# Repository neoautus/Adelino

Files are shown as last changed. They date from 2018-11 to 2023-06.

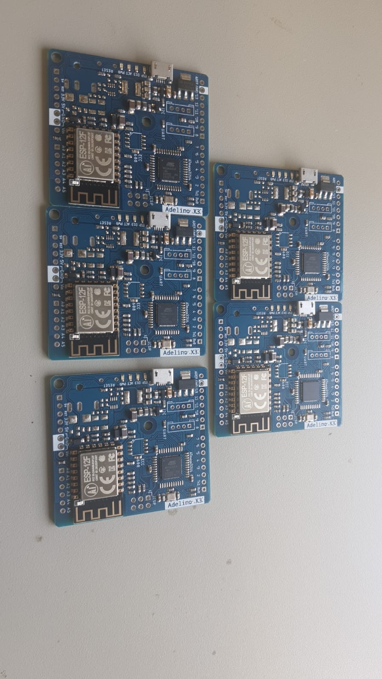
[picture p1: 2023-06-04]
Pics/Adelinos_testados.jpeg

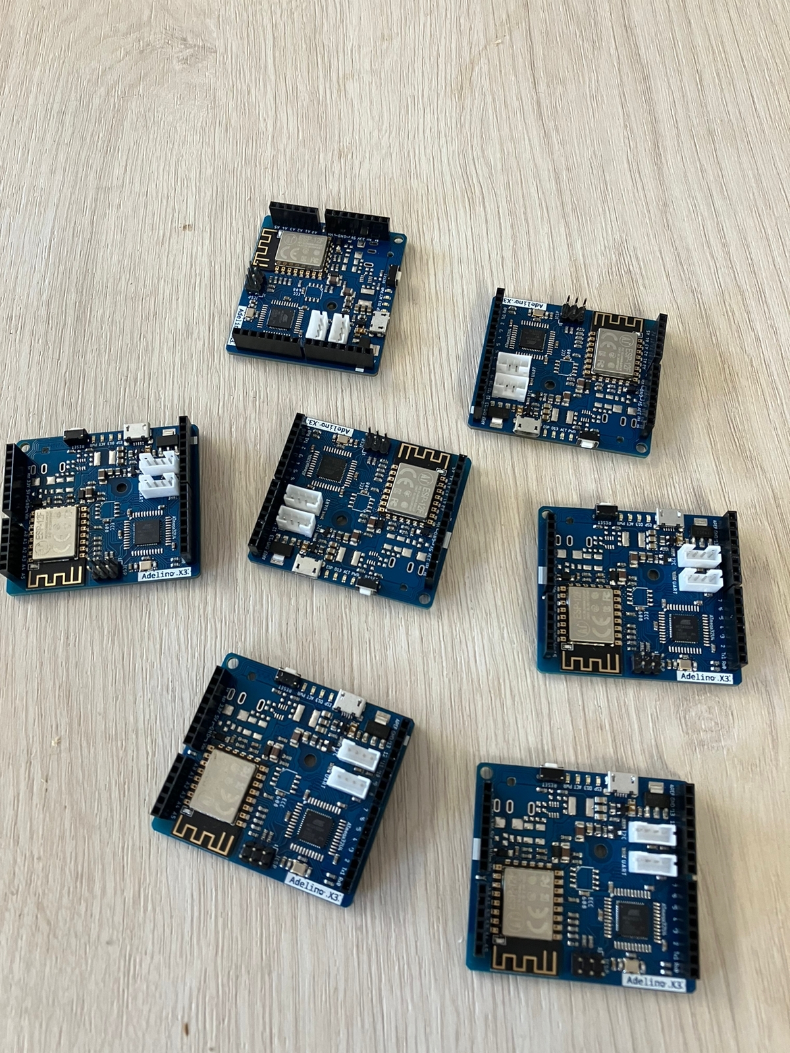
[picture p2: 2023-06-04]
Pics/Adelinos_festando.jpeg

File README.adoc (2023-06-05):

= Adelino
:page-layout: book

O Adelino é uma placa de desenvolvimento baseada no ATmega32U4 com um módulo ESP-12F integrado.
Ela foi inicialmente inspirada no Arduino Leonardo e no Arduino Yún.

Visite nosso https://github.com/neoautus/Adelino/wiki[Wiki] para conhecer melhor este produto!

'''

Adelino is an ATmega32U4 development board with integrated ESP-12F module.
It was initially inspired by Arduino Leonardo and Arduino Yún.

Visit our https://github.com/neoautus/Adelino/wiki[Wiki] for more information!

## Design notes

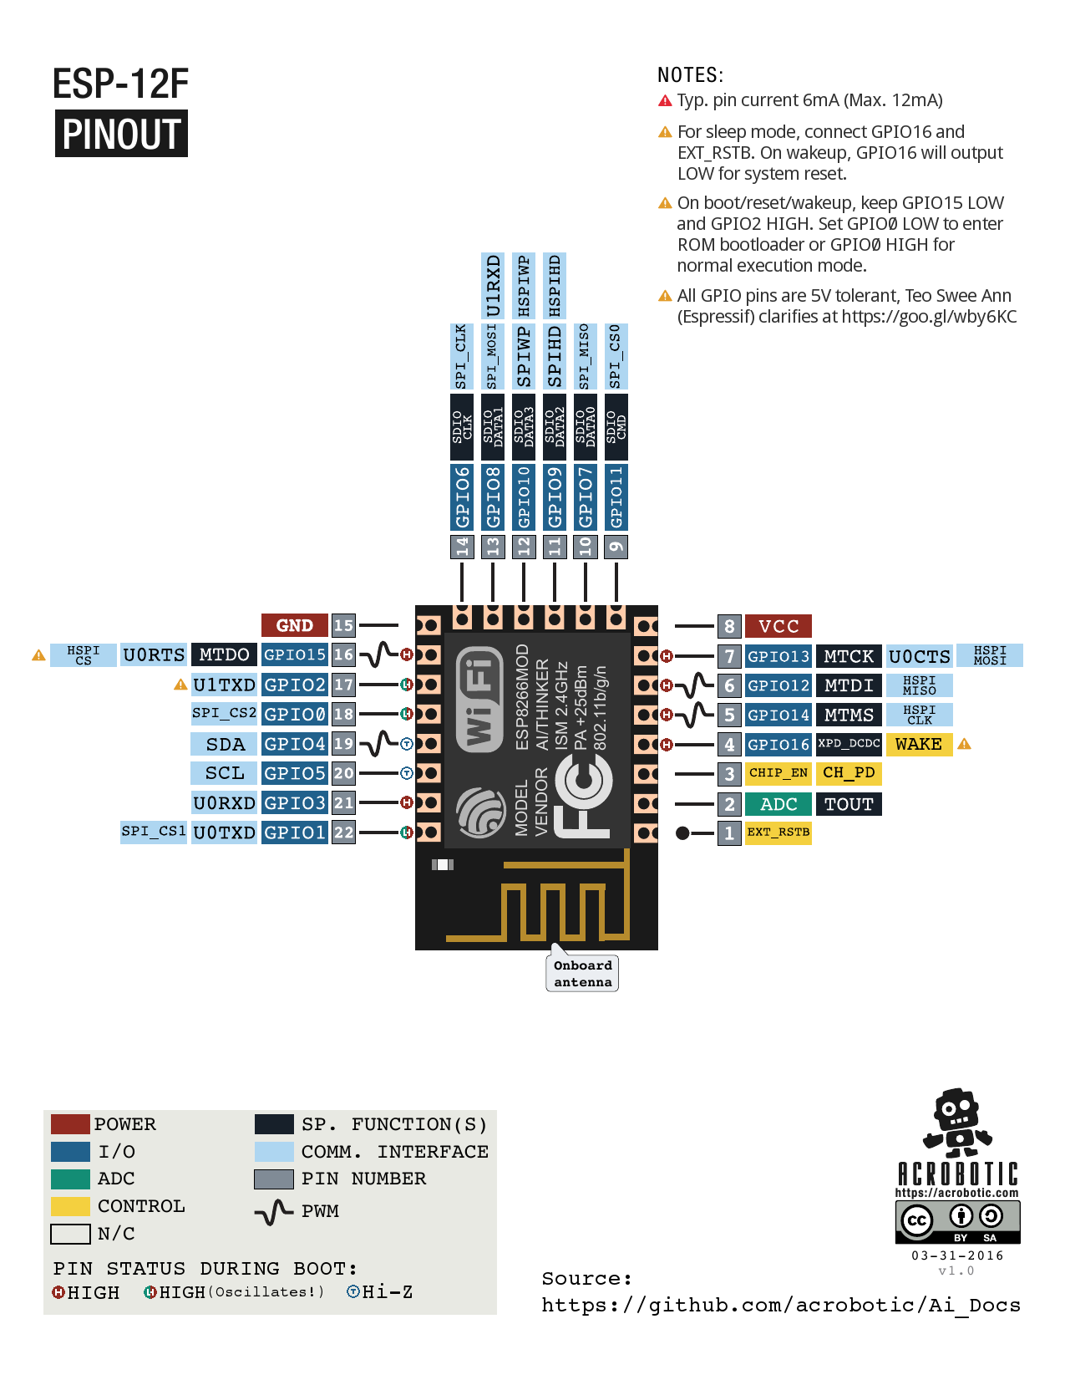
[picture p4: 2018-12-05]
Docs/ESP-12F_Pinout.png

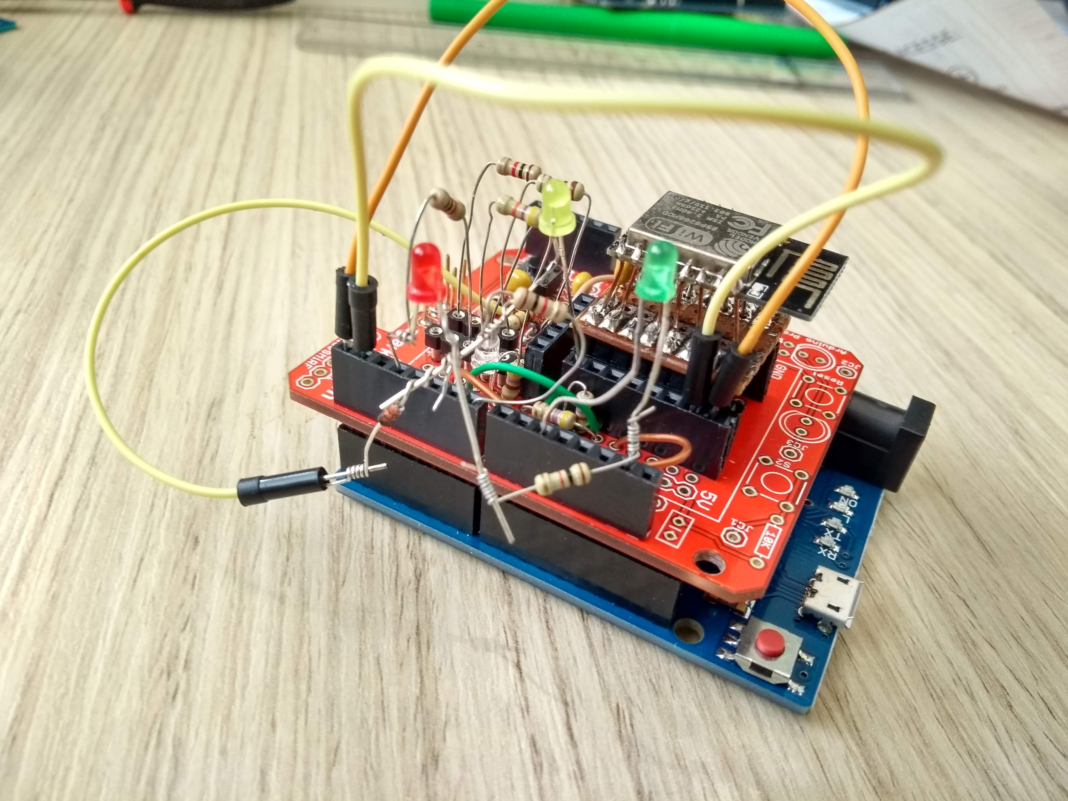
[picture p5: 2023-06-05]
Pics/Prototipagem_adelino.jpg

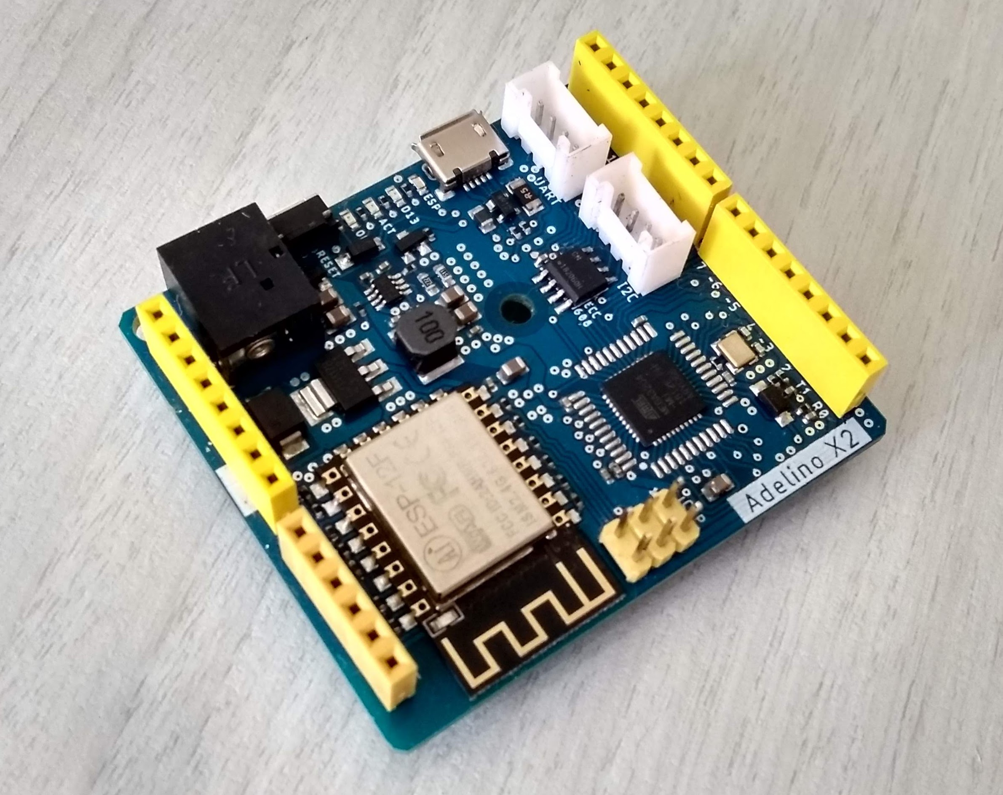
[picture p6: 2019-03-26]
Adelino_X2.jpg

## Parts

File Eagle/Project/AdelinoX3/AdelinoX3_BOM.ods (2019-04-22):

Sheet: AdelinoX3_BOM_Eagle
Parts | Qty | Value | Device | Package | Description | DESC | LABEL | MOUSER_REF | MPN | R | SKU | TP_SIGNAL_NAME | VALUE
C1, C2, C3, C4 | 4 | 22uf | CERAMIC-22UF-16V-10%-X7R(1206) | C1206 | 302010182
C14, C15 | 2 | 22pf | CERAMIC-22PF-50V-5%-NPO(0603) | C0603 | 302010143 |  |  |  | CC0603JRNPO9BN220 |  |  |  | 22pf
C22 | 1 | 1uf | CERAMIC-1UF-25V-10%-X7R(0603) | C0603 | 302010139 |  |  |  | CC0603KRX7R8BB105 |  |  |  | 1uf
C5, C7, C12, C13, C16, C17, C18, C19, C20, C21, C23 | 11 | 100nf | CERAMIC-100NF-50V-10%-X7R(0603) | C0603 | 302010138 |  |  |  | CC0603KRX7R9BB104 |  |  |  | 100nf
C6 | 1 | 22nf | CERAMIC-22NF-50V-10%-X7R(0603) | C0603 | 302010095 |  |  |  | CC0603KRX7R9BB223 |  |  |  | 22nf
C8, C9, C10, C11 | 4 | 10uf | CERAMIC-10UF-25V-10%-X5R(0805) | C0805 | 302010178 |  |  |  | CC0805KKX5R8BB106 |  |  |  | 10uf
D1 | 1 | TVS-DIODE-SZOPL-SMBJ15CA-13-F | TVS-DIODE-SZOPL-SMBJ15CA-13-F | DO-214AA | SMBJ15CA-13-F |  |  |  | SMBJ15CA-13-F |  | SHENZHEN-OPL | TVS DIODE 15VWM 24.4VC SMB
D2, D3 | 2 | 20V-500MA | SMD-DIODE-SCHOTTKY-20V-500MA(SOD-123)P | SOD-123 | 304020028 |  |  |  | MBR0520LT1G |  |  |  | 20V-500MA
D4 | 1 | BLUE-0603 | SMD-LED-CLEAR-BLUE(0603) | LED-0603 | 304090045 |  | ESP |  | 19-217-BHC-ZL1M2RY-3T |  |  |  | BLUE-0603
D5 | 1 | GREEN-0603 | SMD-LED-CLEAR-GREEN(0603) | LED-0603 | 304090043 |  | PWR |  | 19-217-G7C-AN1P2-3T |  |  |  | GREEN-0603
D6 | 1 | YELLOW-0603 | SMD-LED-CLEAR-YELLOW(0603) | LED-0603 | 304090044 |  | ACT |  | 19-217-Y5C-AM1N1VY-3T |  |  |  | YELLOW-0603
D7 | 1 | YEL-0603 | SMD-LED-CLEAR-YELLOW(0603) | LED-0603 | 304090044 |  | D13 |  | 19-217-Y5C-AM1N1VY-3T |  |  |  | YELLOW-0603
ESD1 | 1 | PRTR5V0U2X | SMD-DIODE-TVS-5.5V | SOT-143B | 304050022 |  |  |  | NXP | PRTR5V0U2X,215 |  | 304050022
F1 | 1 | SMD1206R500SF | SMD-PPTC-500MA(1206) | F1206 | 307010002 |  |  |  | SMD1206R500SF |  |  |  | SMD1206R500SF
J1 | 1 | DC-044-A | JACK-DC-044-A | DCJ3P-11.6X9.6X7.0MM | 320120002 |  |  |  | JACK-DC-044-A |  |  |  | DC-044-A
J2, J4, J5 | 3 | YELLOW-8P-2.54 | DIP-YELLOW-FEMALE-HEADER(8P-2.54) | H8-2.54 | 320030065 |  |  |  | F185-1108A1BSYC1 |  |  |  | YELLOW-8P-2.54
J3 | 1 | YELLOW-6P-2.54 | DIP-YELLOW-FEMALE-HEADER-VERT(6P-2.54) | H6-2.54 | 320030019 |  |  |  | F185-1106A1BSYA3 |  |  |  | YELLOW-6P-2.54
J6, J8 | 2 | 4P-2.0 | GROVE-CONNECTOR-DIP(4P-2.0) | HW4-2.0 | 320110033 |  |  |  |  |  |  |  | 4P-2.0
J7 | 1 | YELLOW-2X3P-2.54 | DIP-YELLOW-MALE-HEADER-VERT(2X3P-2.54) | H2X3-2.54 | 320020027 |  |  |  | P125-1203A0BS116A2 |  |  |  | YELLOW-2X3P-2.54
L1, L4 | 2 | 470R-2A | SMD-FERRITE-BEAD-470R-2A(0805)'0805' | L0805 | 303030008 |  |  |  | WLB2012-471T20 |  |  |  | 470R-2A
L2 | 1 | 330R-1500MA | SMD-FERRITE-BEAD-330R-1500MA(0805)'0805' | L0805 | 303030006 |  |  |  | BLM21PG331SN1D |  |  |  | 330R-1500MA
L3 | 1 | 10UH-225MA | SMD-INDUCTOR-10UH-20%-2.35A(2P-5X5X4MM) | L5040S | 303010147
Q1 | 1 | NCE3407A | SMD-MOSFET-P-CH-VDC=30V-ID=4.3A-NCE3407A(SOT-23) | SOT-23 | 305030010 |  |  |  | NCE3407A |  |  |  | NCE3407A
Q2 | 1 | CJ2305 | SMD-MOSFET-P-CH-8V-4.1A-CJ2305(SOT-23) | SOT-23 | 305030014 |  |  |  | CJ2305 |  |  |  | CJ2305
R1, R9, R10, R11, R21 | 5 | 100K | SMD-RES-100K-5%-1/10W(0603) | R0603 | 301010089 |  |  |  | RC0603JR-07100KL |  |  |  | 100K 1/10W
R12, R14, R15, R24, R29 | 5 | 10K | SMD-RES-10K-5%-1/10W(0603) | R0603 | 301010293 |  |  |  | RC0603JR-0710KL |  |  |  | 10K 1/10W
R13 | 1 | 1M | SMD-RES-1M-5%-1/10W(0603) | R0603 | 301010100 |  |  |  | RC0603JR-071ML |  |  |  | 1M 1/10W
R16, R17, R18, R19, R22, R23, R25, R26, R27, R28 | 10 | 1K | SMD-RES-1K-5%-1/10W(0603) | R0603 | 301010291 |  |  |  | RC0603JR-071KL |  |  |  | 1K 1/10W
R2 | 1 | 24K | SMD-RES-24K-1%-1/10W(0603) | R0603 | 301010232
R20 | 1 | 0R | SMD-RES-0R-5%-1/10W(0603) | R0603 | 301010292 |  |  |  | RC0603JR-070RL |  |  |  | 0R
R3, R4 | 2 | 22R | SMD-RES-22R-5%-1/10W(0603) | R0603 | 301010289 |  |  |  | RC0603JR-0722RL |  |  |  | 22R
R30 | 1 | 470R | SMD-RES-470R-5%-1/10W(0603) | R0603 | 301010088 |  |  |  | RC0603JR-07470RL |  |  |  | 470R
R5 | 1 | 10R | SMD-RES-10R-1%-1/10W(0603) | R0603 | 301010185 |  |  |  | RC0603FR-0710RL |  |  |  | 10R
R6 | 1 | 3.3K | SMD-RES-3.3K-5%-1/10W(0603) | R0603 | 301010112
R7 | 1 | 3K / 1% | SMD-RES-510R-1%-1/10W(0603) | R0603 | 301010215 |  |  |  |  | 510R / 1%
R8 | 1 | 2K7 / 1% | SMD-RES-2.7K-1%-1/10W(0603) | R0603 | 301010193 |  |  |  |  | 2K7 / 1%
SW1 | 1 | TS-1101F | DIP-BUTTON(2P-6.0X3.0X4.3MM)-TS-1101F | SW2-5.0-6.0X3.0X4.3MM | 311020025 |  |  |  | TS-1101F |  |  |  | TS-1101F
U1 | 1 | CJT1117-3.3 | PMIC-CJT1117-3.3(SOT223) | SOT-223 | 310030097 |  |  |  | CJT1117-3.3 |  |  |  | CJT1117-3.3-SOT223
U2 | 1 | MP1496DJ-SOT23-8 | PMIC-MP1496DJ(SOT23-8) | SOT-23-8 | 310030121 |  |  |  | MP1496DJ |  |  |  | MP1496DJ-SOT23-8
U3 | 1 | ESP-12F / OPL: 317060163 | ESP-12F | ESP-12F | 317060163
U4 | 1 | DNP | ATECC608(SOIC8) | SOIC8-1.27-5X4MM | ATECC608A-SSHDA-B (SOIC-8) | ATECC608A-SSHDA-B (SOIC-8) |  | https://www.mouser.com/ProductDetail/556-ATECC608ASSHDAB | ATECC608A-SSHDA-B |  |  |  | ATECC608-SOIC8
U5 | 1 | ATMEGA32U4-MUR-QFN44 | MCU-ATMEGA32U4-MUR(VQFN44) | QFN44G-0.5-7X7MM | 310010016 | Primary socket - QFN44 |  |  | ATMEGA32U4-MUR |  |  |  | ATMEGA32U4-MUR-QFN44
USB1 | 1 | ST-USB-001G | MICRO-USB-SMD-B-WITHOUT-POST-W/P(ST-USB-001G) | MICRO-USB5+4P-SMD-0.65-B | 320010000 |  |  |  | ST-USB-001G |  |  |  | ST-USB-001G
X1 | 1 | 306010049_XTAL_16MHZ-3225_4P | 306010049_XTAL_16MHZ-3225_4P | X3225_4P | 306010049

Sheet: AdelinoX3_BOM_Seeed
Designator | MPN / Seeed SKU | Qty | Link
C1, C2, C3, C4 | 302010182 | 4
C14, C15 | 302010143 | 2
C22 | 302010139 | 1
C5, C7, C12, C13, C16, C17, C18, C19, C20, C21, C23 | 302010138 | 11
C6 | 302010095 | 1
C8, C9, C10, C11 | 302010178 | 4
D1 | SMBJ15CA-13-F | 1 | ShenZhen OPL
D2, D3 | 304020028 | 2
D4 | 304090045 | 1
D5 | 304090043 | 1
D6 | 304090044 | 1
D7 | 304090044 | 1
ESD1 | 304050022 | 1
F1 | 307010002 | 1
J1 | 320120002 | 1
J2, J4, J5 | 320030065 | 3
J3 | 320030019 | 1
J6, J8 | 320110033 | 2
J7 | 320020027 | 1
L1, L4 | 303030008 | 2
L2 | 303030006 | 1
L3 | 303010147 | 1
Q1 | 305030010 | 1
Q2 | 305030014 | 1
R1, R9, R10, R11, R21 | 301010089 | 5
R12, R14, R15, R24, R29 | 301010293 | 5
R13 | 301010100 | 1
R16, R17, R18, R19, R22, R23, R25, R26, R27, R28 | 301010291 | 10
R2 | 301010232 | 1
R20 | 301010292 | 1
R3, R4 | 301010289 | 2
R30 | 301010088 | 1
R5 | 301010185 | 1
R6 | 301010112 | 1
R7 | 301010215 | 1
R8 | 301010193 | 1
SW1 | 311020025 | 1
U1 | 310030097 | 1
U2 | 310030121 | 1
U3 | 317060163 | 1
U4 | ATECC608A-SSHDA-B (SOIC-8) | 1 | https://www.mouser.com/ProductDetail/556-ATECC608ASSHDAB
U5 | 310010016 | 1
USB1 | 320010000 | 1
X1 | 306010049 | 1

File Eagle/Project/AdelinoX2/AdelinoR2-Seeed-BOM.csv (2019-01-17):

Designator | MPN / Seeed SKU | Qty | Link
C1, C4, C5, C8, C11, C14, C15, C16, C17, C18, C19, C21 | 302010024 | 12
C12, C13 | 302010018 | 2
C2, C3, C6, C9, C10 | 302010178 | 5
C20 | 302010179 | 1
C7 | 302010242 | 1
D1 | SMBJ15CA-13-F | 1 | ShenZhen OPL
D2, D5 | 304020028 | 2
D3 | 304090043 | 1
D4 | 304090044 | 1
D6 | 304090044 | 1
D7 | 304090045 | 1
ESD1 | 304050022 | 1
F1 | 307010002 | 1
J1 | 320120002 | 1
J2, J4, J5 | 320030065 | 3
J3 | 320030019 | 1
J6, J8 | 320110033 | 2
J7 | 320020027 | 1
L1 | 303030006 | 1
L2 | 303010147 | 1
Q1 | 305030010 | 1
Q2 | 305030014 | 1
R1, R8, R9, R10 | 301010456 | 4
R11, R13, R14, R20, R23, R29 | 301010047 | 6
R12 | 301010043 | 1
R15, R16, R17, R18, R21, R22, R24, R25, R26, R27 | 301010006 | 10
R19 | 301010000 | 1
R2, R3 | 301010052 | 2
R28 | 301010013 | 1
R4 | 301010444 | 1
R5 | 301010035 | 1
R6 | 301010215 | 1
R7 | 301010193 | 1
SW1 | 311020025 | 1
U1 | 310030097 | 1
U2 | 310030121 | 1
U3 | 317060163 | 1
U5 | 310010016 | 1
USB1 | 320010000 | 1
X1 | 306010049 | 1

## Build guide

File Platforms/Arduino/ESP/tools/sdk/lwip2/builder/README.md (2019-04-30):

# lwIP-2 from original source

This repo offers a link layer for esp82xx-nonos-sdk-2.
The original goal is to try and use a recent lwIP version for stability reasons.
Currently lwIP-v2 is implemented, other IP stacks could be tried.

current lwIP link: [STABLE_2.1.2](http://git.savannah.nongnu.org/cgit/lwip.git/tree/?h=STABLE-2_1_2_RELEASE)

# Status

* UDP/TCP codes using lwIP-1.4 need some updates - two examples: [arduino](https://github.com/esp8266/Arduino/pull/3129) and [sming](https://github.com/SmingHub/Sming/pull/1147)
* IPv6 working in Arduino
* SACK-out enabled in Arduino
* tcp is more stable ([example1](https://github.com/esp8266/Arduino/issues/3075) and [example2](https://github.com/esp8266/Arduino/issues/2925))
* used by default in esp8266 arduino core
* accepted pull request in [esp8266/arduino](https://github.com/esp8266/Arduino/pull/3783)
* (WIP) [sming](https://github.com/SmingHub/Sming/pull/1147)
* (WIP) [esp-open-sdk](https://github.com/pfalcon/esp-open-sdk/pull/271)

# Build

[with Arduino](https://github.com/esp8266/Arduino/tree/master/tools/sdk/lwip2)

# MSS

Remember the MSS footprint: 4\*MSS bytes in RAM per tcp connection.
The lowest recommanded value is 536.

# How it works

Espressif binary libraries rely on their lwip implementation. The idea, as
described in this [comment](https://github.com/kadamski/esp-lwip/issues/8)
is to wrap espressif calls, and rewrite them for a new tcp implementation.

Example with lwip1.4's ethernet_input() called by espressif binary blobs
finally reaching lwip2's:

```
-- LWIP2-----------------------------------
#define ethernet_input ethernet_input_LWIP2
- lwip2's ethernet_input_LWIP2_is called
                            (/ \)
                             | |
-- glue (new side)-----------^-v-----------
                             | |
glue_ethernet_input          | |
- maps structures glue->new  |
- calls ethernet_input_LWIP2(^ v)
- maps structures new->glue    |
                             | |
-- glue (old side)-----------^-v-----------
                             | |
ethernet_input():            | |
- maps structures old->glue  | 
- calls glue_ethernet_input (^ v)
- maps structures glue->old    |
                             | |
- espressif blobs -----------^-v-----------
XXXXXXXXXXXXXXXXXXXXXXXXXXXX | | XXXXXXXXXX
wifi calls    ethernet_input(/ \) XXXXXXXXX
XXXXXXXXXXXXXXXXXXXXXXXXXXXXXXXXXXXXXXXXXXX
-------------------------------------------
```

# History

Original [cleaning and port](https://github.com/nekromant/esp8266-frankenstein/tree/master/src/contrib/lwipupdate) of espressif's patch set from lwIP-v1.4 to lwIP-v2 with references to lwIP-git-sha1

[Discussion](https://github.com/kadamski/esp-lwip/issues/8) on how further work could done

[First](https://github.com/d-a-v/esp8266-phy) version of this implementation

[Second](https://github.com/esp8266/Arduino/pull/3206) version for arduino only

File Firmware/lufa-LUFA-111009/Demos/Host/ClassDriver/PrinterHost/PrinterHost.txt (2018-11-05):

/** \file
 *
 *  This file contains special DoxyGen information for the generation of the main page and other special
 *  documentation pages. It is not a project source file.
 */

/** \mainpage Printer Host Demo
 *
 *  \section Sec_Compat Demo Compatibility:
 *
 *  The following list indicates what microcontrollers are compatible with this demo.
 *
 *  - Series 7 USB AVRs (AT90USBxxx7)
 *
 *  \section Sec_Info USB Information:
 *
 *  The following table gives a rundown of the USB utilization of this demo.
 *
 *  <table>
 *   <tr>
 *    <td><b>USB Mode:</b></td>
 *    <td>Host</td>
 *   </tr>
 *   <tr>
 *    <td><b>USB Class:</b></td>
 *    <td>Printer Device</td>
 *   </tr>
 *   <tr>
 *    <td><b>USB Subclass:</b></td>
 *    <td>Bidirectional Protocol</td>
 *   </tr>
 *   <tr>
 *    <td><b>Relevant Standards:</b></td>
 *    <td>USBIF Printer Class Specification \n
 *        PCL Language Specification</td>
 *   </tr>
 *   <tr>
 *    <td><b>Usable Speeds:</b></td>
 *    <td>Low Speed Mode \n
 *        Full Speed Mode</td>
 *   </tr>
 *  </table>
 *
 *  \section Sec_Description Project Description:
 *
 *  Printer host demonstration application. This gives a simple reference
 *  application for implementing a USB Printer host, for USB printers using
 *  the bidirectional data encapsulation protocol and PCL language.
 *
 *  Upon connection of a compatible printer, the printer's device ID is sent
 *  to the AVR's serial port, and a simple test page is printed using the PCL
 *  printer language.
 *
 *  \section Sec_Options Project Options
 *
 *  The following defines can be found in this demo, which can control the demo behaviour when defined, or changed in value.
 *
 *  <table>
 *   <tr>
 *    <td>
 *     None
 *    </td>
 *   </tr>
 *  </table>
 */

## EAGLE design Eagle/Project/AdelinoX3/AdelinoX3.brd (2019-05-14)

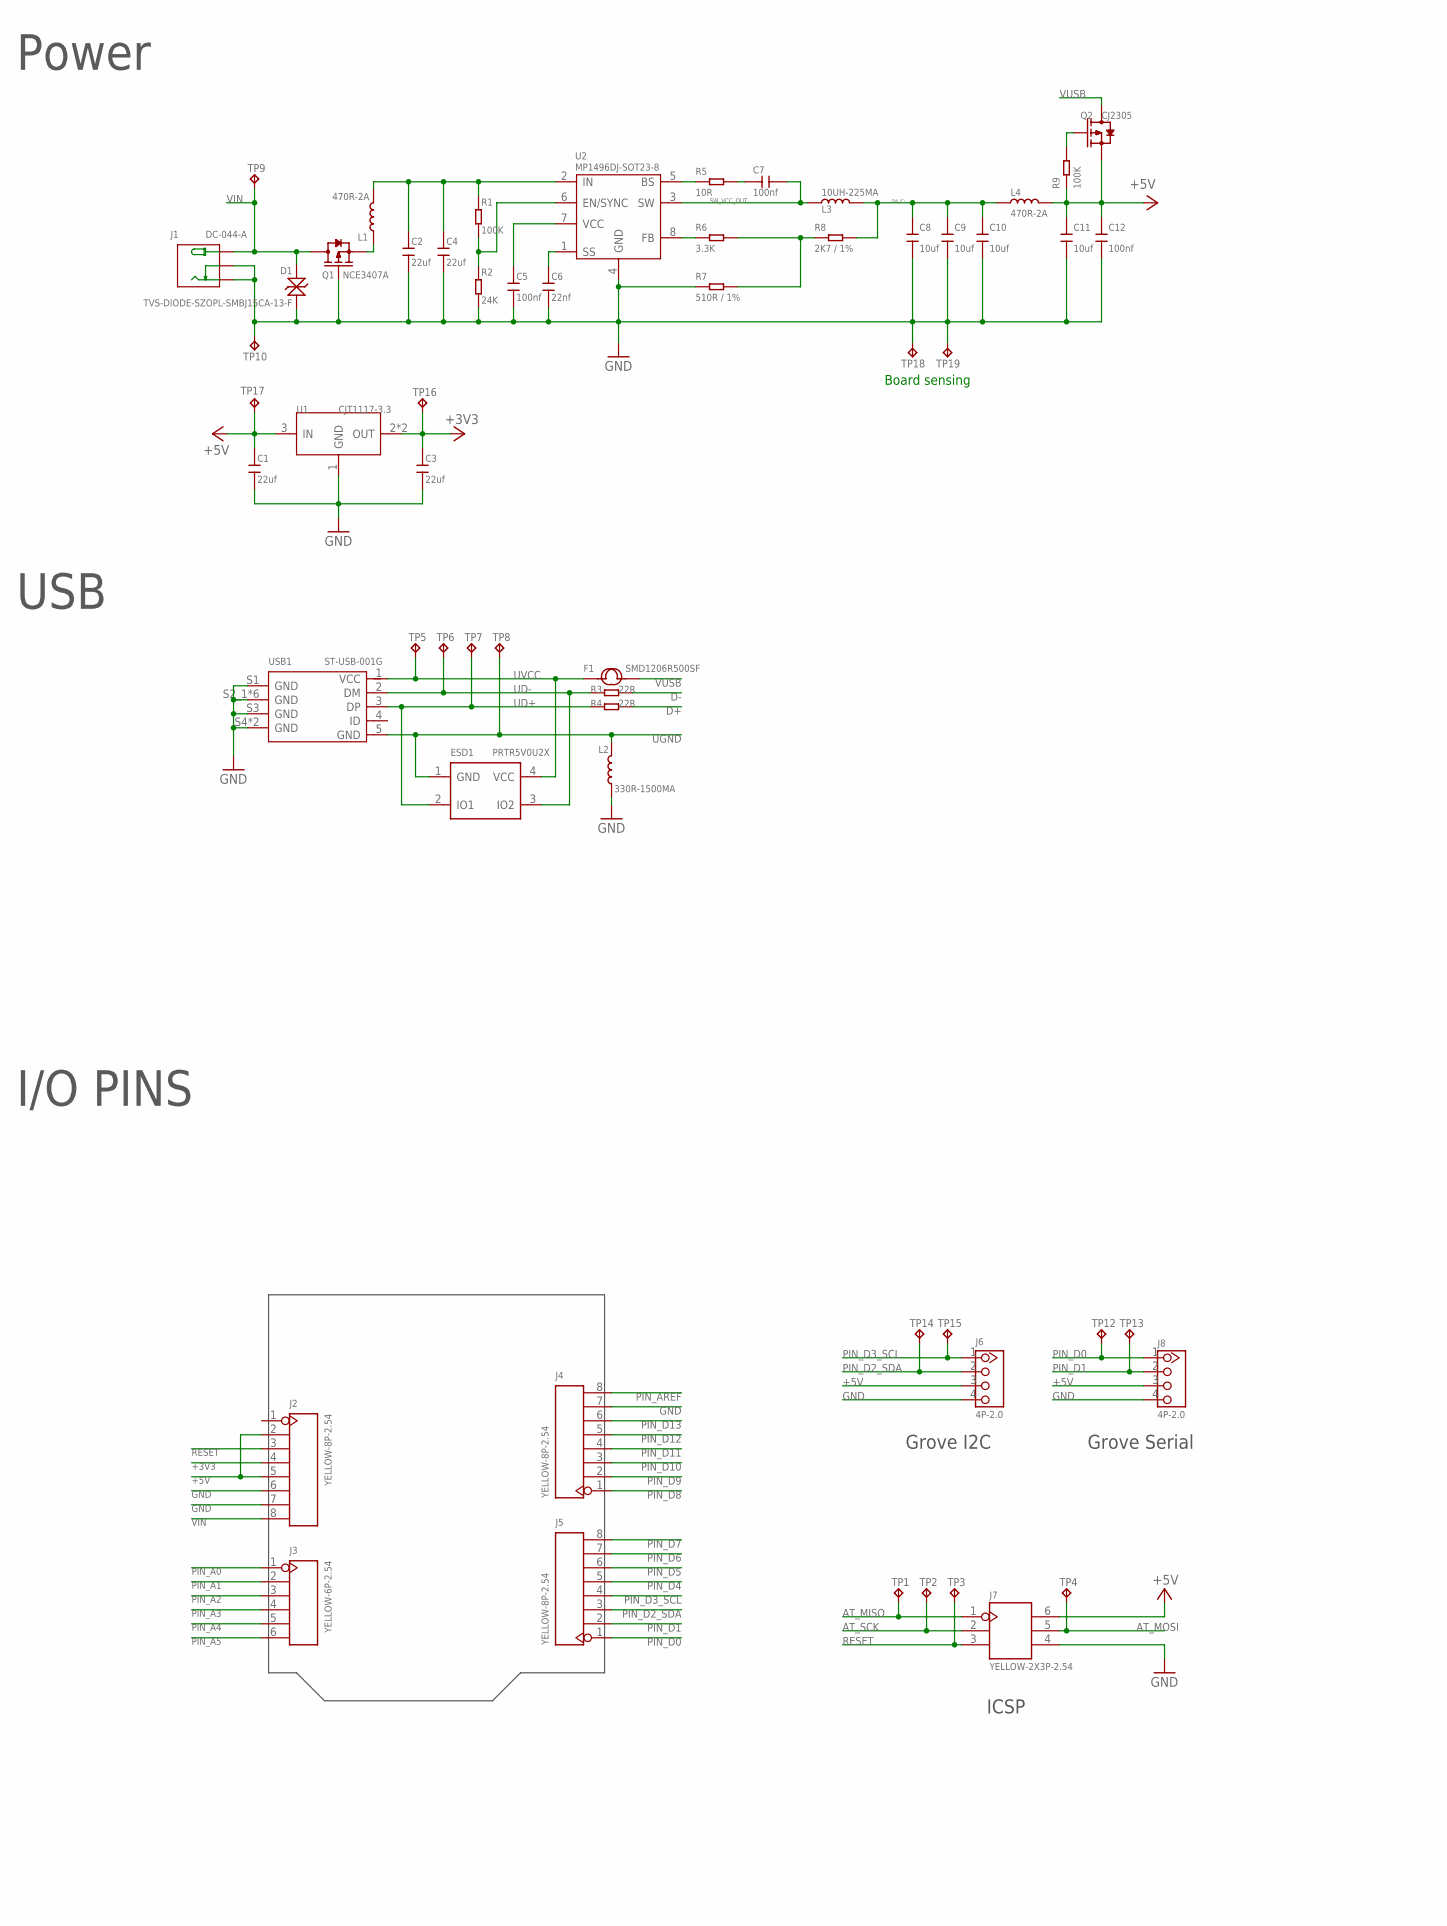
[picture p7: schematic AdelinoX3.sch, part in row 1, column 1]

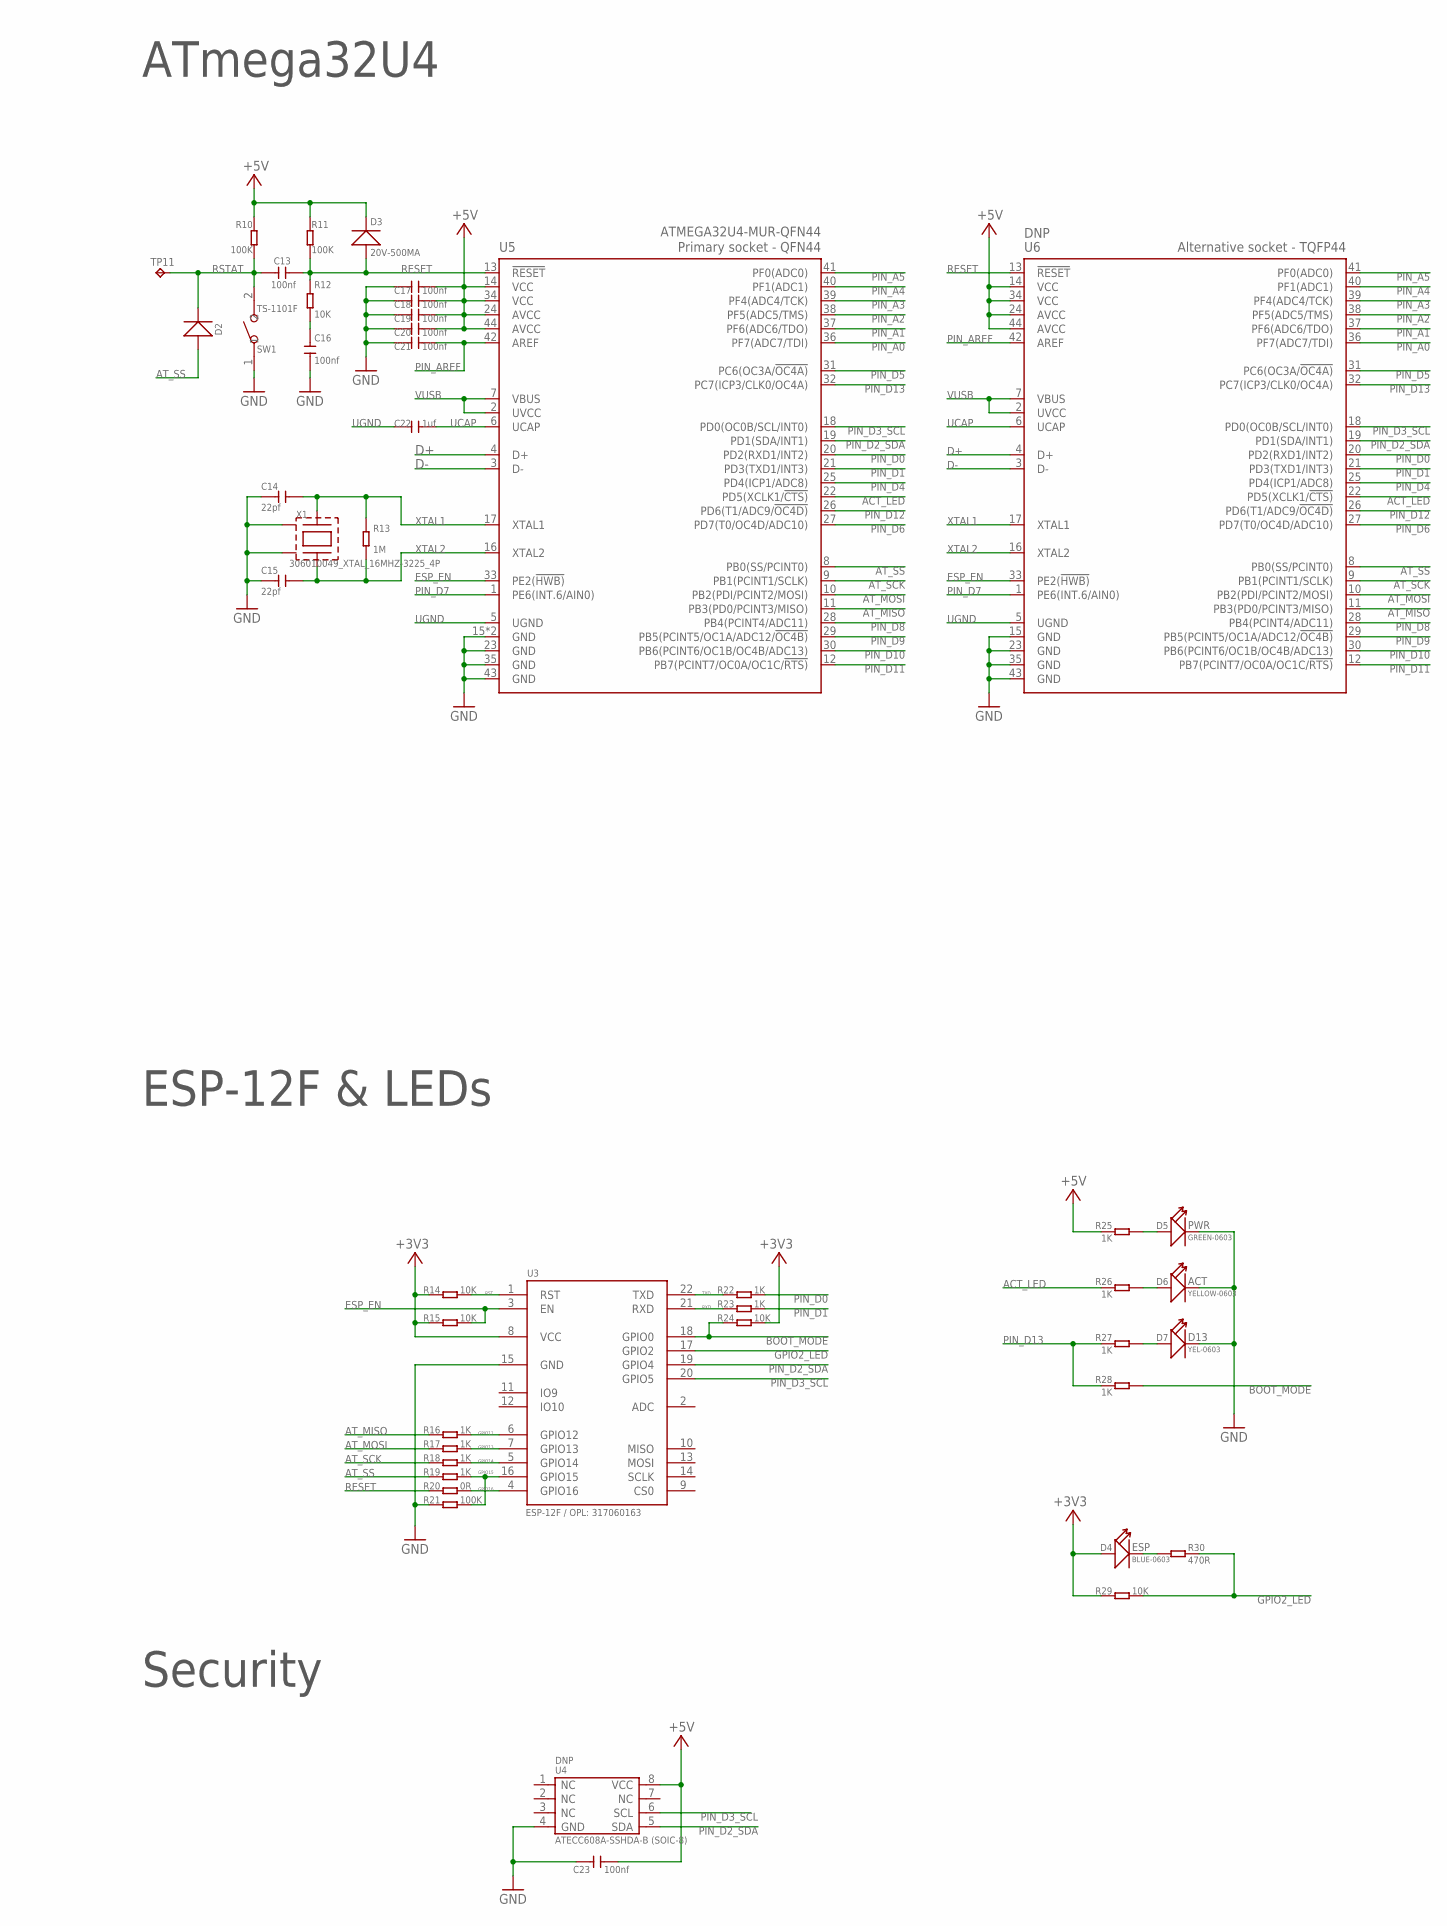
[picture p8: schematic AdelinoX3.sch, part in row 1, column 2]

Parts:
C1, C2, C3, C4: 22uf; C1206
C5, C7, C12, C13, C16, C17, C18, C19, C20, C21, C23: 100nf; C0603
C6: 22nf; C0603
C8, C9, C10, C11: 10uf; C0805
C14, C15: 22pf; C0603
C22: 1uf; C0603
D1: TVS-DIODE-SZOPL-SMBJ15CA-13-F; DO-214AA
D2, D3: 20V-500MA; SOD-123
D4: BLUE-0603; LED-0603
D5: GREEN-0603; LED-0603
D6: YELLOW-0603; LED-0603
D7: YEL-0603; LED-0603
ESD1: PRTR5V0U2X; SOT-143B
F1: SMD1206R500SF; F1206
J1: DC-044-A; DCJ3P-11.6X9.6X7.0MM
J2, J4, J5: YELLOW-8P-2.54; H8-2.54
J3: YELLOW-6P-2.54; H6-2.54
J6, J8: 4P-2.0; HW4-2.0
J7: YELLOW-2X3P-2.54; H2X3-2.54
L1, L4: 470R-2A; L0805
L2: 330R-1500MA; L0805
L3: 10UH-225MA; L5040S
Q1: NCE3407A; SOT-23
Q2: CJ2305; SOT-23
R1, R9, R10, R11, R21: 100K; R0603
R2: 24K; R0603
R3, R4: 22R; R0603
R5: 10R; R0603
R6: 3.3K; R0603
R7: 3K / 1%; R0603
R8: 2K7 / 1%; R0603
R12, R14, R15, R24, R29: 10K; R0603
R13: 1M; R0603
R16, R17, R18, R19, R22, R23, R25, R26, R27, R28: 1K; R0603
R20: 0R; R0603
R30: 470R; R0603
SW1: TS-1101F; SW2-5.0-6.0X3.0X4.3MM
TP1, TP2, TP3, TP4, TP5, TP6, TP7, TP8, TP9, TP10, TP11, TP12, TP13, TP14, TP15, TP16, TP17, TP18, TP19: TPTP16R; TP16R
U1: CJT1117-3.3; SOT-223
U2: MP1496DJ-SOT23-8; SOT-23-8
U3: ESP-12F / OPL: 317060163; ESP-12F
U4: DNP; SOIC8-1.27-5X4MM; MPN ATECC608A-SSHDA-B
U5: ATMEGA32U4-MUR-QFN44; QFN44G-0.5-7X7MM
U6: DNP; TQFP44-0.8-9.6X9.6MM
USB1: ST-USB-001G; MICRO-USB5+4P-SMD-0.65-B
X1: 306010049_XTAL_16MHZ-3225_4P; X3225_4P

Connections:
+3V3: C3.2, D4.+, J2.4, R14.1, R15.1, R24.2, R29.1, TP16.TP, U1.2 (OUT), U1.TER (OUT), U3.8 (VCC)
+5V: C1.2, C11.2, C12.2, C17.1, C18.1, C19.1, C20.1, C23.1, D3.-, J2.2, J2.5, J6.3, J7.6, J8.3, L4.2, Q2.2 (S), R9.1, R10.1, R11.2, R25.1, TP17.TP, U1.3 (IN), U4.8 (VCC), U5.14 (VCC), U5.24 (AVCC), U5.34 (VCC), U5.44 (AVCC), U6.14 (VCC), U6.24 (AVCC), U6.34 (VCC), U6.44 (AVCC)
ACT_LED: R26.1, U5.22 (PD5(XCLK1/!CTS)), U6.22 (PD5(XCLK1/!CTS))
AT_MISO: J7.1, R16.1, TP1.TP, U5.11 (PB3(PD0/PCINT3/MISO)), U6.11 (PB3(PD0/PCINT3/MISO))
AT_MOSI: J7.5, R17.1, TP4.TP, U5.10 (PB2(PDI/PCINT2/MOSI)), U6.10 (PB2(PDI/PCINT2/MOSI))
AT_SCK: J7.2, R18.1, TP2.TP, U5.9 (PB1(PCINT1/SCLK)), U6.9 (PB1(PCINT1/SCLK))
AT_SS: D2.+, R19.1, U5.8 (PB0(SS/PCINT0)), U6.8 (PB0(SS/PCINT0))
BOOT_MODE: R24.1, R28.2, U3.18 (GPIO0)
D+: R4.2, U5.4 (D+), U6.4 (D+)
D-: R3.2, U5.3 (D-), U6.3 (D-)
ESP_EN: R15.2, U3.3 (EN), U5.33 (PE2(!HWB)), U6.33 (PE2(!HWB))
GND: C1.1, C2.1, C3.1, C4.1, C5.1, C6.1, C8.1, C9.1, C10.1, C11.1, C12.1, C14.1, C15.1, C16.2, C17.2, C18.2, C19.2, C20.2, C21.2, C23.2, D1.+, D5.-, D6.-, D7.-, J1.CDN1 (CDN), J1.CDN2 (CDN), J1.CDN3 (CDN), J1.CDN4 (CDN), J1.GND1 (-), J1.GND2 (-), J1.GND3 (-), J1.GND4 (-), J2.6, J2.7, J4.7, J6.4, J7.4, J8.4, L2.1, Q1.1 (G), R2.1, R7.1, R21.1, SW1.1, TP10.TP, TP18.TP, TP19.TP, U1.1 (GND), U2.4 (GND), U3.15 (GND), U4.4 (GND), U5.15 (GND), U5.23 (GND), U5.35 (GND), U5.43 (GND), U5.TAB (GND), U6.15 (GND), U6.23 (GND), U6.35 (GND), U6.43 (GND), USB1.S1 (GND), USB1.S2_1 (GND), USB1.S2_2 (GND), USB1.S2_3 (GND), USB1.S3 (GND), USB1.S4 (GND), USB1.S5_1 (GND), USB1.S5_2 (GND), USB1.S5_3 (GND), USB1.S6 (GND), X1.P$2 (GND1), X1.P$4 (GND2)
GPIO2_LED: R29.2, R30.2, U3.17 (GPIO2)
GPIO12: R16.2, U3.6 (GPIO12)
GPIO13: R17.2, U3.7 (GPIO13)
GPIO14: R18.2, U3.5 (GPIO14)
GPIO15: R19.2, R21.2, U3.16 (GPIO15)
GPIO16: R20.2, U3.4 (GPIO16)
unnamed: Q2.1 (G), R9.2
unnamed: R1.2, R2.2, U2.6 (EN/SYNC)
unnamed: L1.1, Q1.2 (S)
unnamed: C16.1, R12.2
unnamed: C7.2, R5.2
unnamed: R6.2, R7.2, R8.1
PIN_A0: J3.1, U5.36 (PF7(ADC7/TDI)), U6.36 (PF7(ADC7/TDI))
PIN_A1: J3.2, U5.37 (PF6(ADC6/TDO)), U6.37 (PF6(ADC6/TDO))
PIN_A2: J3.3, U5.38 (PF5(ADC5/TMS)), U6.38 (PF5(ADC5/TMS))
PIN_A3: J3.4, U5.39 (PF4(ADC4/TCK)), U6.39 (PF4(ADC4/TCK))
PIN_A4: J3.5, U5.40 (PF1(ADC1)), U6.40 (PF1(ADC1))
PIN_A5: J3.6, U5.41 (PF0(ADC0)), U6.41 (PF0(ADC0))
PIN_AREF: C21.1, J4.8, U5.42 (AREF), U6.42 (AREF)
PIN_D0: J5.1, J8.1, R22.2, TP12.TP, U5.20 (PD2(RXD1/INT2)), U6.20 (PD2(RXD1/INT2))
PIN_D1: J5.2, J8.2, R23.2, TP13.TP, U5.21 (PD3(TXD1/INT3)), U6.21 (PD3(TXD1/INT3))
PIN_D2_SDA: J5.3, J6.2, TP14.TP, U3.19 (GPIO4), U4.5 (SDA), U5.19 (PD1(SDA/INT1)), U6.19 (PD1(SDA/INT1))
PIN_D3_SCL: J5.4, J6.1, TP15.TP, U3.20 (GPIO5), U4.6 (SCL), U5.18 (PD0(OC0B/SCL/INT0)), U6.18 (PD0(OC0B/SCL/INT0))
PIN_D4: J5.5, U5.25 (PD4(ICP1/ADC8)), U6.25 (PD4(ICP1/ADC8))
PIN_D5: J5.6, U5.31 (PC6(OC3A/!OC4A)), U6.31 (PC6(OC3A/!OC4A))
PIN_D6: J5.7, U5.27 (PD7(T0/OC4D/ADC10)), U6.27 (PD7(T0/OC4D/ADC10))
PIN_D7: J5.8, U5.1 (PE6(INT.6/AIN0)), U6.1 (PE6(INT.6/AIN0))
PIN_D8: J4.1, U5.28 (PB4(PCINT4/ADC11)), U6.28 (PB4(PCINT4/ADC11))
PIN_D9: J4.2, U5.29 (PB5(PCINT5/OC1A/ADC12/!OC4B)), U6.29 (PB5(PCINT5/OC1A/ADC12/!OC4B))
PIN_D10: J4.3, U5.30 (PB6(PCINT6/OC1B/OC4B/ADC13)), U6.30 (PB6(PCINT6/OC1B/OC4B/ADC13))
PIN_D11: J4.4, U5.12 (PB7(PCINT7/OC0A/OC1C/!RTS)), U6.12 (PB7(PCINT7/OC0A/OC1C/!RTS))
PIN_D12: J4.5, U5.26 (PD6(T1/ADC9/!OC4D)), U6.26 (PD6(T1/ADC9/!OC4D))
PIN_D13: J4.6, R27.1, R28.1, U5.32 (PC7(ICP3/CLK0/OC4A)), U6.32 (PC7(ICP3/CLK0/OC4A))
RESET: C13.1, D3.+, J2.3, J7.3, R11.1, R12.1, R20.1, TP3.TP, U5.13 (!RESET), U6.13 (!RESET)
RST: R14.2, U3.1 (RST)
RSTAT: C13.2, D2.-, R10.2, SW1.2, TP11.TP
RXD: R23.1, U3.21 (RXD)
SW_BS: R5.1, U2.5 (BS)
SW_F1: C8.2, C9.2, C10.2, L3.2, L4.1, R8.2
SW_FB: R6.1, U2.8 (FB)
SW_SS: C6.2, U2.1 (SS)
SW_VCAP: C5.2, U2.7 (VCC)
SW_VCC_IN: C2.2, C4.2, L1.2, R1.1, U2.2 (IN)
SW_VCC_OUT: C7.1, L3.1, U2.3 (SW)
TXD: R22.1, U3.22 (TXD)
UCAP: C22.2, U5.6 (UCAP), U6.6 (UCAP)
UD+: ESD1.2 (IO1), R4.1, TP7.TP, USB1.3 (DP)
UD-: ESD1.3 (IO2), R3.1, TP6.TP, USB1.2 (DM)
UGND: C22.1, ESD1.1 (GND), L2.2, TP8.TP, U5.5 (UGND), U6.5 (UGND), USB1.5 (GND)
UVCC: ESD1.4 (VCC), F1.1, TP5.TP, USB1.1 (VCC)
VIN: D1.-, J1.VCC1 (+), J1.VCC2 (+), J1.VCC3 (+), J1.VCC4 (+), J2.8, Q1.3 (D), TP9.TP
VUSB: F1.2, Q2.3 (D), U5.2 (UVCC), U5.7 (VBUS), U6.2 (UVCC), U6.7 (VBUS)
XTAL1: C14.2, R13.2, U5.17 (XTAL1), U6.17 (XTAL1), X1.P$1
XTAL2: C15.2, R13.1, U5.16 (XTAL2), U6.16 (XTAL2), X1.P$3
_ACT: D6.+, R26.2
_D13: D7.+, R27.2
_ESP: D4.-, R30.1
_PWR: D5.+, R25.2

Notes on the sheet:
USB
Power
ATmega32U4
ESP-12F & LEDs
I/O PINS
Grove I2C
Grove Serial
Security
ICSP
Board sensing

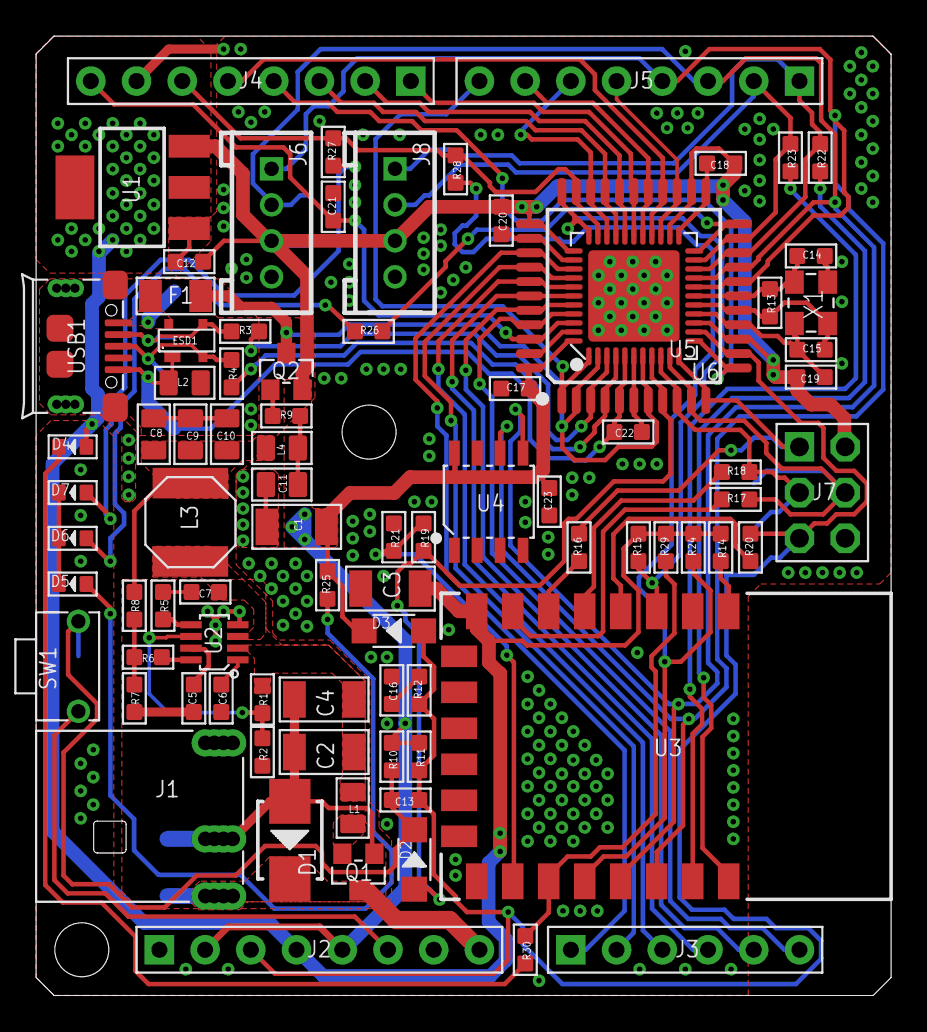
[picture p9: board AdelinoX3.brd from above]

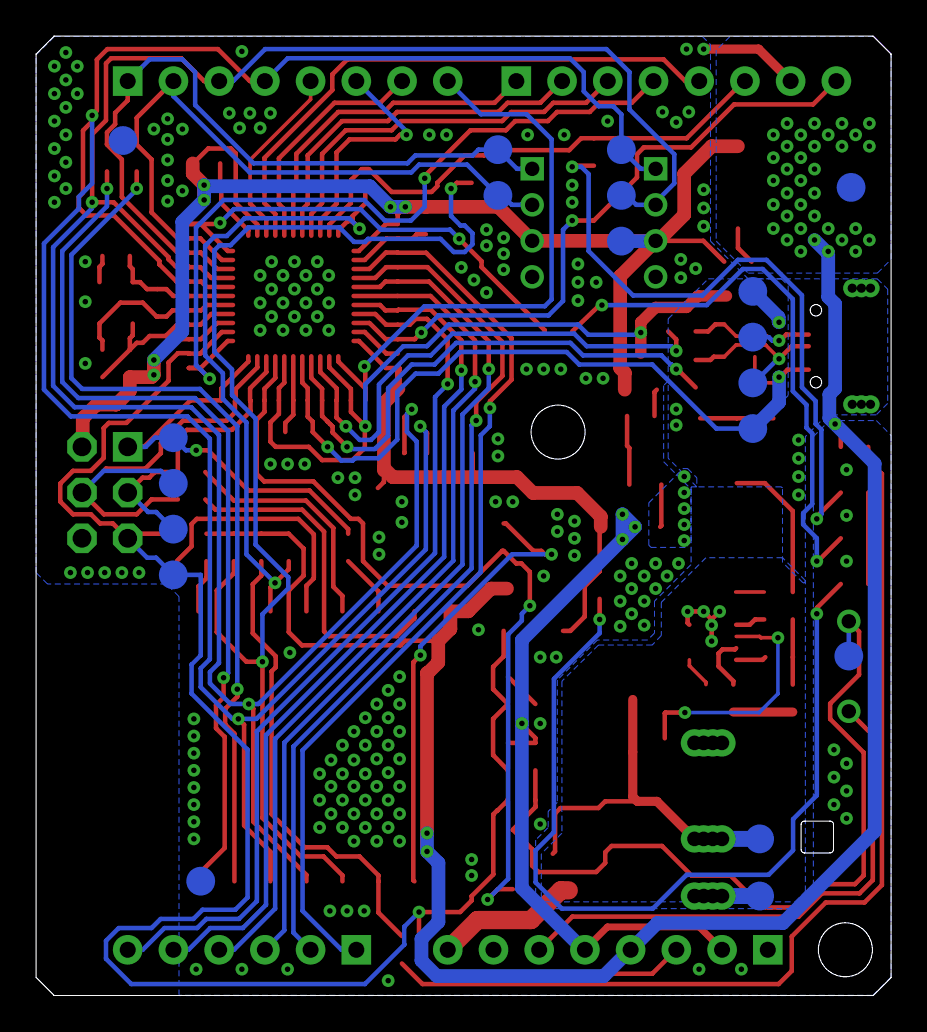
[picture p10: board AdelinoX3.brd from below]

Board: 2 copper layers, 47.5 x 53.3 mm, 104 parts (19 on the bottom side), 70 nets.

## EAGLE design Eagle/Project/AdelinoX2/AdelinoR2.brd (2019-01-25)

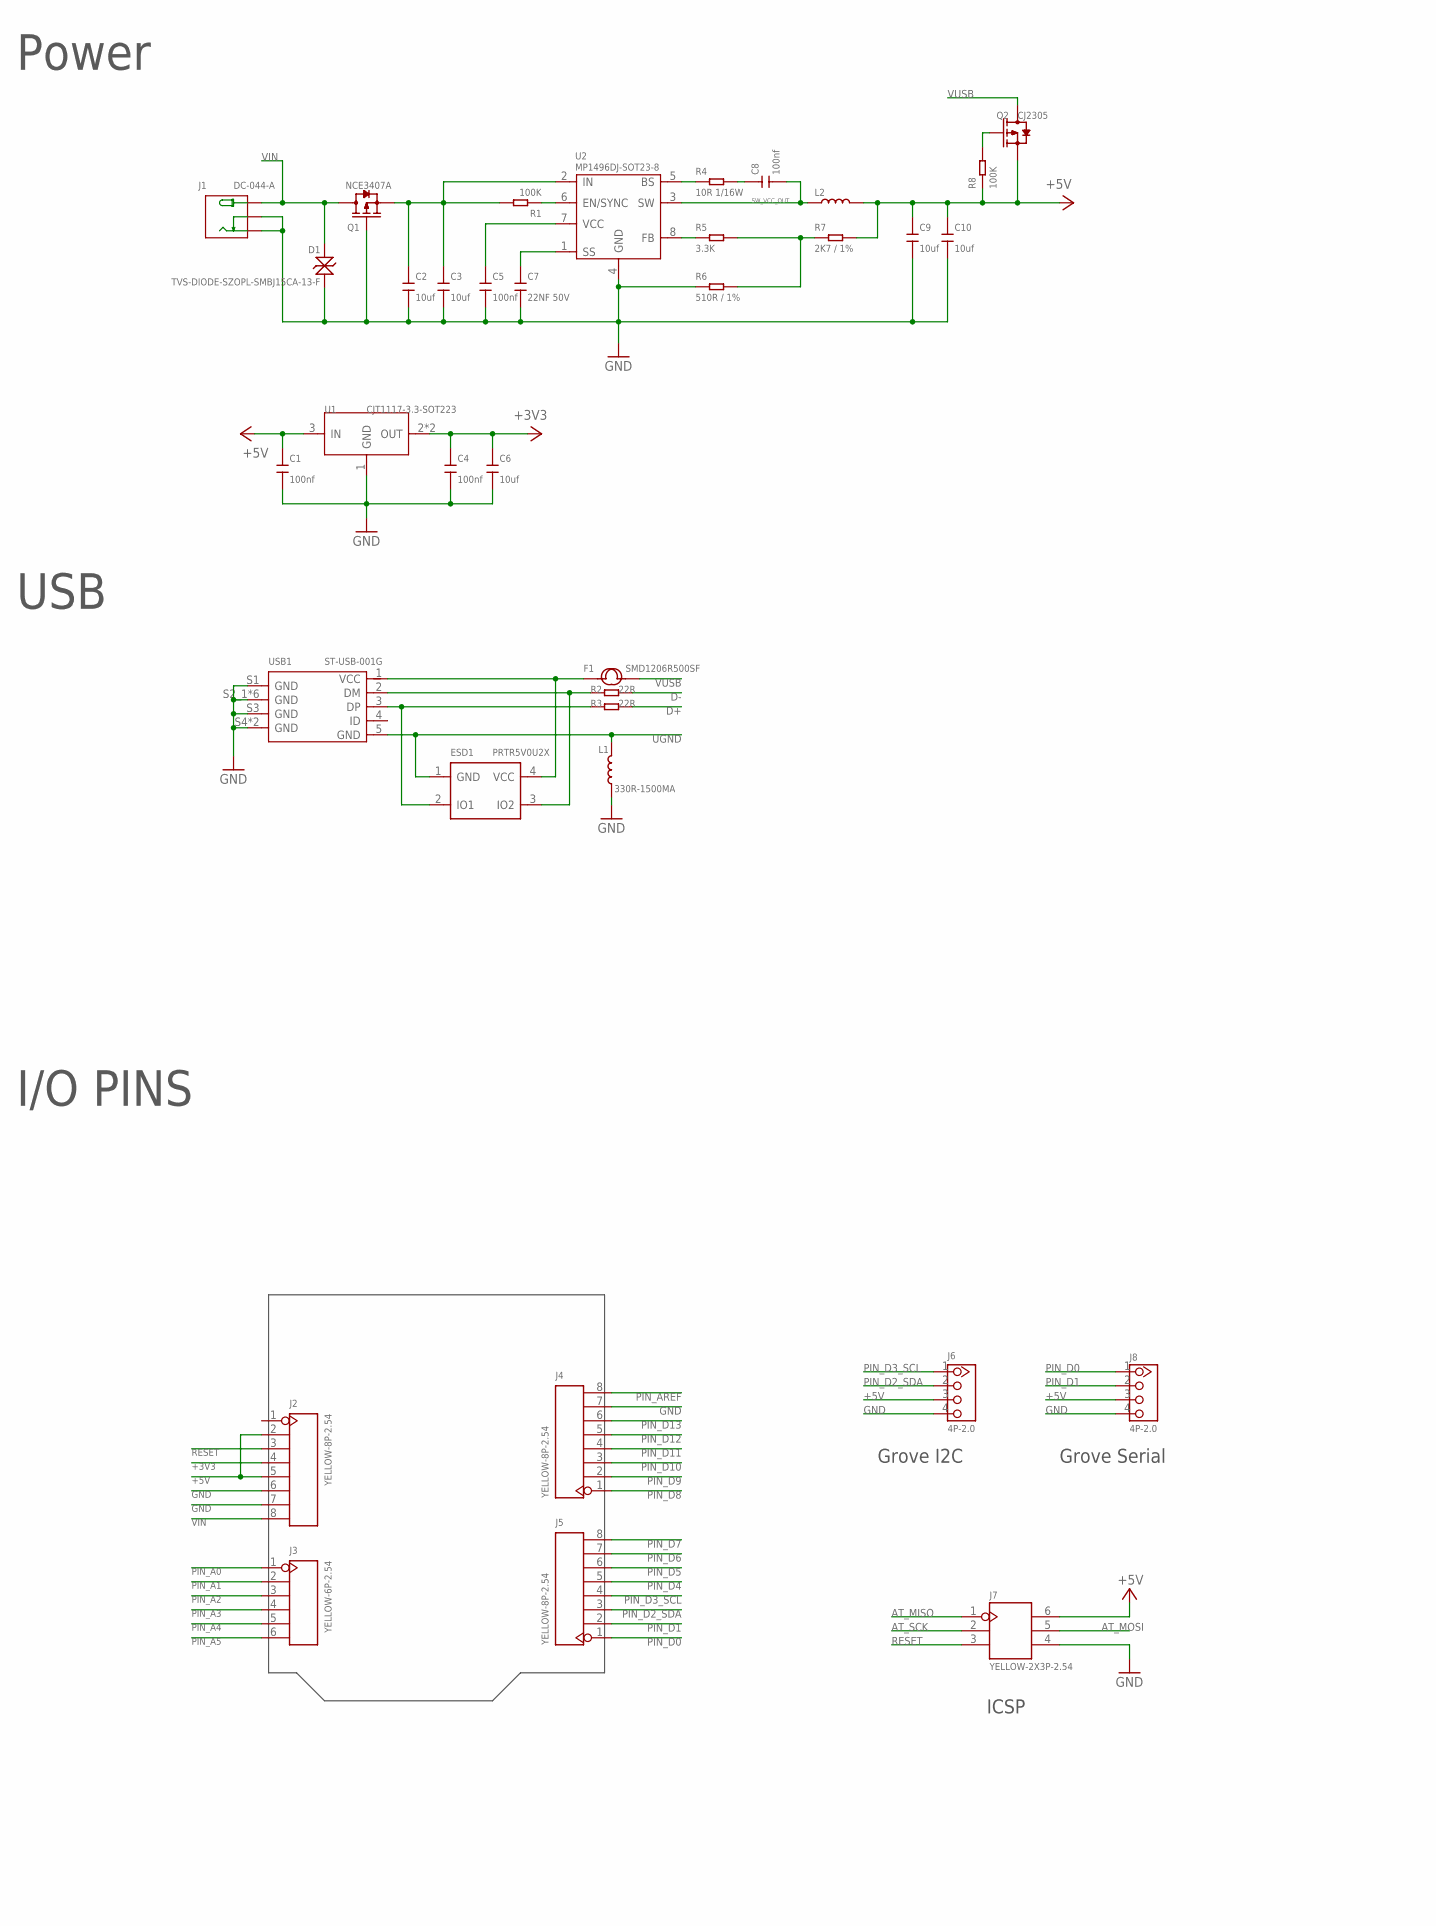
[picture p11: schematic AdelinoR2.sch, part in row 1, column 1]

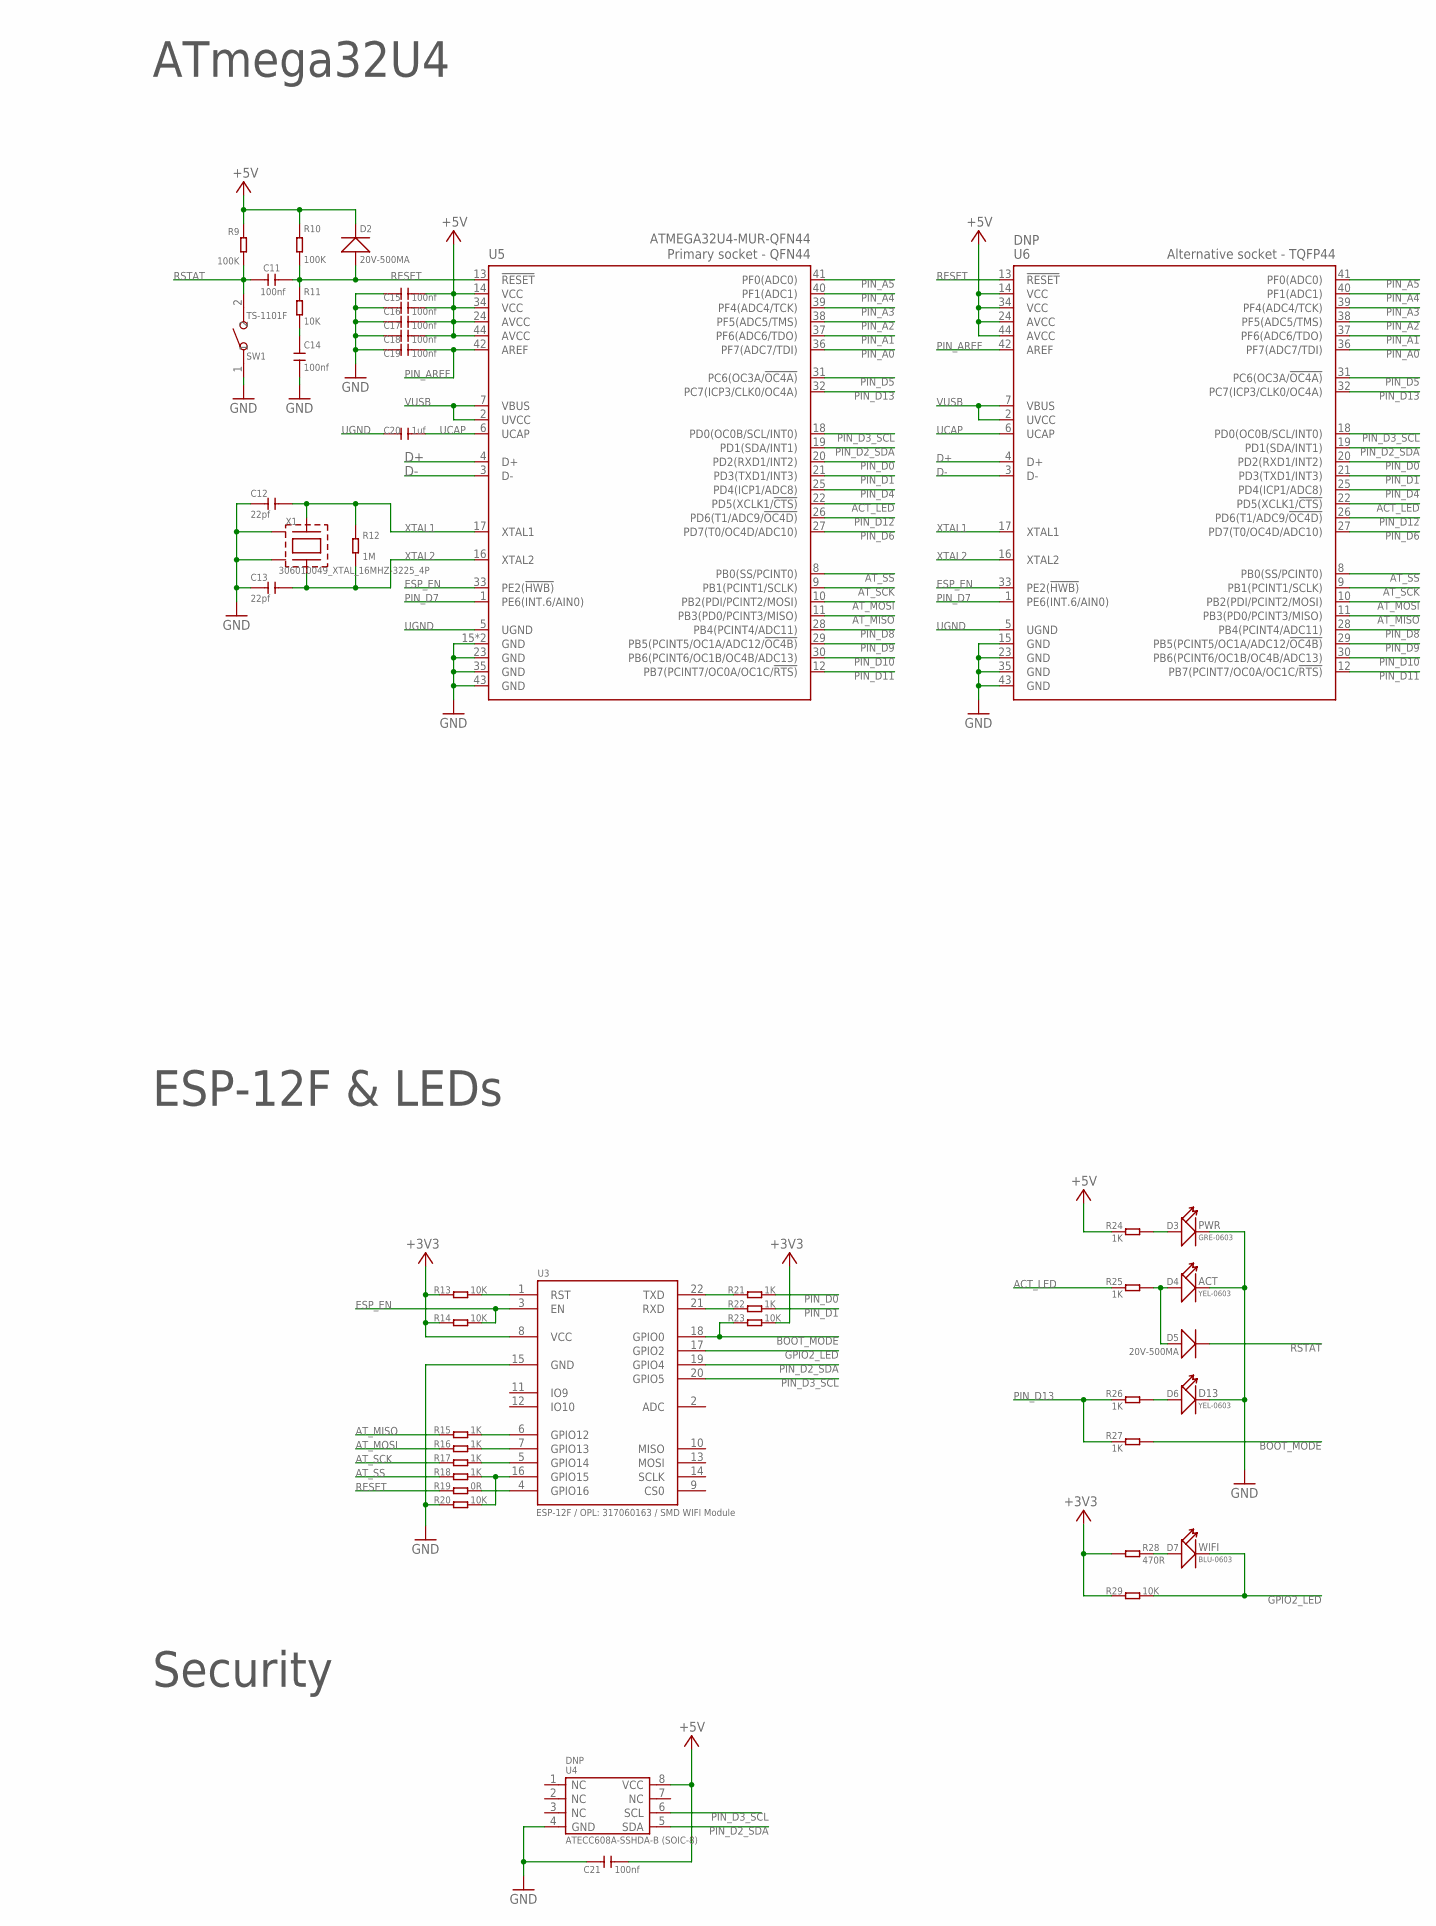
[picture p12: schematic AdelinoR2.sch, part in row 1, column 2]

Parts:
C1, C4, C5, C8, C11, C14, C15, C16, C17, C18, C19, C21: 100nf; C0402
C2, C3, C6, C9, C10: 10uf; C0805
C7: 22NF 50V; C0402
C12, C13: 22pf; C0402
C20: 1uf; C0805
D1: TVS-DIODE-SZOPL-SMBJ15CA-13-F; DO-214AA
D2, D5: 20V-500MA; SOD-123
D3: GRE-0603; LED-0603
D4, D6: YEL-0603; LED-0603
D7: BLU-0603; LED-0603
ESD1: PRTR5V0U2X; SOT-143B
F1: SMD1206R500SF; F1206
J1: DC-044-A; DCJ3P-11.6X9.6X7.0MM
J2, J4, J5: YELLOW-8P-2.54; H8-2.54
J3: YELLOW-6P-2.54; H6-2.54
J6, J8: 4P-2.0; HW4-2.0
J7: YELLOW-2X3P-2.54; H2X3-2.54
L1: 330R-1500MA; L0805
L2: 10UH-225MA; L5040S
Q1: NCE3407A; SOT-23
Q2: CJ2305; SOT-23
R1, R8, R9, R10: 100K; R0402
R2, R3: 22R; R0402
R4: 10R 1/16W; R0402
R5: 3.3K; R0402
R6: 3K / 1%; R0603
R7: 2K7 / 1%; R0603
R11, R13, R14, R20, R23, R29: 10K; R0402
R12: 1M; R0402
R15, R16, R17, R18, R21, R22, R24, R25, R26, R27: 1K; R0402
R19: 0R; R0402
R28: 470R; R0402
SW1: TS-1101F; SW2-5.0-6.0X3.0X4.3MM
U1: CJT1117-3.3-SOT223; SOT-223
U2: MP1496DJ-SOT23-8; SOT-23-8
U3: ESP-12F / OPL: 317060163 / SMD WIFI Module; ESP-12F
U4: DNP; SOIC8-1.27-5X4MM; MPN ATECC608A-SSHDA-B
U5: ATMEGA32U4-MUR-QFN44; QFN44G-0.5-7X7MM
U6: DNP; TQFP44-0.8-9.6X9.6MM
USB1: ST-USB-001G; MICRO-USB5+4P-SMD-0.65-B
X1: 306010049_XTAL_16MHZ-3225_4P; X3225_4P

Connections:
+3V3: C4.2, C6.2, J2.4, R13.1, R14.1, R23.2, R28.1, R29.1, U1.2 (OUT), U1.TER (OUT), U3.8 (VCC)
+5V: C1.2, C9.2, C10.2, C15.1, C16.1, C17.1, C18.1, C21.1, D2.-, J2.2, J2.5, J6.3, J7.6, J8.3, L2.2, Q2.2 (S), R7.2, R8.1, R9.1, R10.2, R24.1, U1.3 (IN), U4.8 (VCC), U5.14 (VCC), U5.24 (AVCC), U5.34 (VCC), U5.44 (AVCC), U6.14 (VCC), U6.24 (AVCC), U6.34 (VCC), U6.44 (AVCC)
ACT_LED: R25.1, U5.22 (PD5(XCLK1/!CTS)), U6.22 (PD5(XCLK1/!CTS))
AT_MISO: J7.1, R15.1, U5.11 (PB3(PD0/PCINT3/MISO)), U6.11 (PB3(PD0/PCINT3/MISO))
AT_MOSI: J7.5, R16.1, U5.10 (PB2(PDI/PCINT2/MOSI)), U6.10 (PB2(PDI/PCINT2/MOSI))
AT_SCK: J7.2, R17.1, U5.9 (PB1(PCINT1/SCLK)), U6.9 (PB1(PCINT1/SCLK))
AT_SS: R18.1, U5.8 (PB0(SS/PCINT0)), U6.8 (PB0(SS/PCINT0))
BOOT_MODE: R23.1, R27.2, U3.18 (GPIO0)
D+: R3.2, U5.4 (D+), U6.4 (D+)
D-: R2.2, U5.3 (D-), U6.3 (D-)
ESP_EN: R14.2, U3.3 (EN), U5.33 (PE2(!HWB)), U6.33 (PE2(!HWB))
GND: C1.1, C2.1, C3.1, C4.1, C5.1, C6.1, C7.1, C9.1, C10.1, C12.1, C13.1, C14.2, C15.2, C16.2, C17.2, C18.2, C19.2, C21.2, D1.+, D3.-, D4.-, D6.-, J1.CDN1 (CDN), J1.CDN2 (CDN), J1.CDN3 (CDN), J1.CDN4 (CDN), J1.GND1 (-), J1.GND2 (-), J1.GND3 (-), J1.GND4 (-), J2.6, J2.7, J4.7, J6.4, J7.4, J8.4, L1.1, Q1.1 (G), R6.1, R20.1, SW1.1, U1.1 (GND), U2.4 (GND), U3.15 (GND), U4.4 (GND), U5.15 (GND), U5.23 (GND), U5.35 (GND), U5.43 (GND), U5.TAB (GND), U6.15 (GND), U6.23 (GND), U6.35 (GND), U6.43 (GND), USB1.S1 (GND), USB1.S2_1 (GND), USB1.S2_2 (GND), USB1.S2_3 (GND), USB1.S3 (GND), USB1.S4 (GND), USB1.S5_1 (GND), USB1.S5_2 (GND), USB1.S5_3 (GND), USB1.S6 (GND), X1.P$2 (GND1), X1.P$4 (GND2)
GPIO2_LED: D7.-, R29.2, U3.17 (GPIO2)
unnamed: ESD1.3 (IO2), R2.1, USB1.2 (DM)
unnamed: ESD1.2 (IO1), R3.1, USB1.3 (DP)
unnamed: Q2.1 (G), R8.2
unnamed: D7.+, R28.2
unnamed: R19.2, U3.4 (GPIO16)
unnamed: ESD1.4 (VCC), F1.1, USB1.1 (VCC)
unnamed: R15.2, U3.6 (GPIO12)
unnamed: C14.1, R11.2
unnamed: R16.2, U3.7 (GPIO13)
unnamed: C8.2, R4.2
unnamed: R21.1, U3.22 (TXD)
unnamed: R22.1, U3.21 (RXD)
unnamed: R17.2, U3.5 (GPIO14)
unnamed: R18.2, R20.2, U3.16 (GPIO15)
unnamed: R13.2, U3.1 (RST)
unnamed: R5.2, R6.2, R7.1
PIN_A0: J3.1, U5.36 (PF7(ADC7/TDI)), U6.36 (PF7(ADC7/TDI))
PIN_A1: J3.2, U5.37 (PF6(ADC6/TDO)), U6.37 (PF6(ADC6/TDO))
PIN_A2: J3.3, U5.38 (PF5(ADC5/TMS)), U6.38 (PF5(ADC5/TMS))
PIN_A3: J3.4, U5.39 (PF4(ADC4/TCK)), U6.39 (PF4(ADC4/TCK))
PIN_A4: J3.5, U5.40 (PF1(ADC1)), U6.40 (PF1(ADC1))
PIN_A5: J3.6, U5.41 (PF0(ADC0)), U6.41 (PF0(ADC0))
PIN_AREF: C19.1, J4.8, U5.42 (AREF), U6.42 (AREF)
PIN_D0: J5.1, J8.1, R21.2, U5.20 (PD2(RXD1/INT2)), U6.20 (PD2(RXD1/INT2))
PIN_D1: J5.2, J8.2, R22.2, U5.21 (PD3(TXD1/INT3)), U6.21 (PD3(TXD1/INT3))
PIN_D2_SDA: J5.3, J6.2, U3.19 (GPIO4), U4.5 (SDA), U5.19 (PD1(SDA/INT1)), U6.19 (PD1(SDA/INT1))
PIN_D3_SCL: J5.4, J6.1, U3.20 (GPIO5), U4.6 (SCL), U5.18 (PD0(OC0B/SCL/INT0)), U6.18 (PD0(OC0B/SCL/INT0))
PIN_D4: J5.5, U5.25 (PD4(ICP1/ADC8)), U6.25 (PD4(ICP1/ADC8))
PIN_D5: J5.6, U5.31 (PC6(OC3A/!OC4A)), U6.31 (PC6(OC3A/!OC4A))
PIN_D6: J5.7, U5.27 (PD7(T0/OC4D/ADC10)), U6.27 (PD7(T0/OC4D/ADC10))
PIN_D7: J5.8, U5.1 (PE6(INT.6/AIN0)), U6.1 (PE6(INT.6/AIN0))
PIN_D8: J4.1, U5.28 (PB4(PCINT4/ADC11)), U6.28 (PB4(PCINT4/ADC11))
PIN_D9: J4.2, U5.29 (PB5(PCINT5/OC1A/ADC12/!OC4B)), U6.29 (PB5(PCINT5/OC1A/ADC12/!OC4B))
PIN_D10: J4.3, U5.30 (PB6(PCINT6/OC1B/OC4B/ADC13)), U6.30 (PB6(PCINT6/OC1B/OC4B/ADC13))
PIN_D11: J4.4, U5.12 (PB7(PCINT7/OC0A/OC1C/!RTS)), U6.12 (PB7(PCINT7/OC0A/OC1C/!RTS))
PIN_D12: J4.5, U5.26 (PD6(T1/ADC9/!OC4D)), U6.26 (PD6(T1/ADC9/!OC4D))
PIN_D13: J4.6, R26.1, R27.1, U5.32 (PC7(ICP3/CLK0/OC4A)), U6.32 (PC7(ICP3/CLK0/OC4A))
RESET: C11.1, D2.+, J2.3, J7.3, R10.1, R11.1, R19.1, U5.13 (!RESET), U6.13 (!RESET)
RSTAT: C11.2, D5.-, R9.2, SW1.2
SW_BS: R4.1, U2.5 (BS)
SW_EN: R1.1, U2.6 (EN/SYNC)
SW_FB: R5.1, U2.8 (FB)
SW_SS: C7.2, U2.1 (SS)
SW_VCAP: C5.2, U2.7 (VCC)
SW_VCC_IN: C2.2, C3.2, Q1.2 (S), R1.2, U2.2 (IN)
SW_VCC_OUT: C8.1, L2.1, U2.3 (SW)
UCAP: C20.2, U5.6 (UCAP), U6.6 (UCAP)
UGND: C20.1, ESD1.1 (GND), L1.2, U5.5 (UGND), U6.5 (UGND), USB1.5 (GND)
VIN: D1.-, J1.VCC1 (+), J1.VCC2 (+), J1.VCC3 (+), J1.VCC4 (+), J2.8, Q1.3 (D)
VUSB: F1.2, Q2.3 (D), U5.2 (UVCC), U5.7 (VBUS), U6.2 (UVCC), U6.7 (VBUS)
XTAL1: C12.2, R12.2, U5.17 (XTAL1), U6.17 (XTAL1), X1.P$1
XTAL2: C13.2, R12.1, U5.16 (XTAL2), U6.16 (XTAL2), X1.P$3
_ACT: D4.+, D5.+, R25.2
_D13: D6.+, R26.2
_PWR: D3.+, R24.2

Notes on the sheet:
USB
Power
ATmega32U4
ESP-12F & LEDs
I/O PINS
Grove I2C
Grove Serial
Security
ICSP

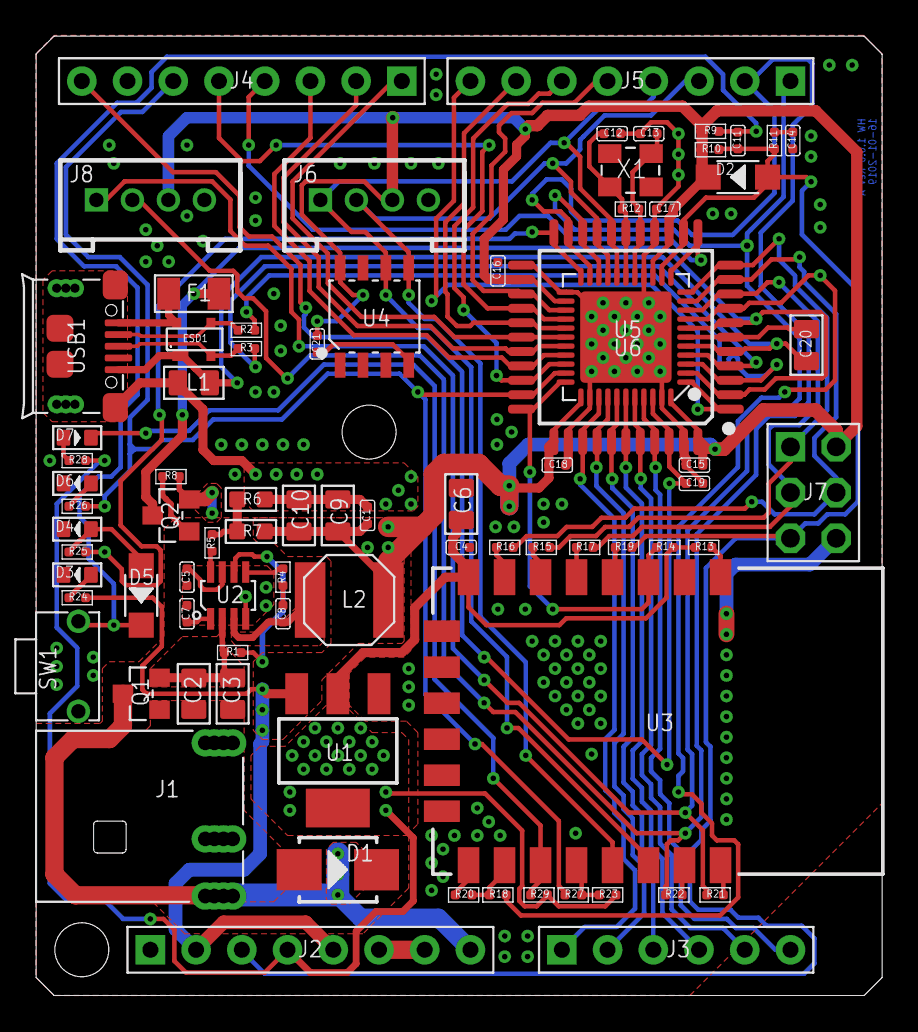
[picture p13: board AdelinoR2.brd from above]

Board: 2 copper layers, 47.0 x 53.3 mm, 80 parts (0 on the bottom side), 68 nets.

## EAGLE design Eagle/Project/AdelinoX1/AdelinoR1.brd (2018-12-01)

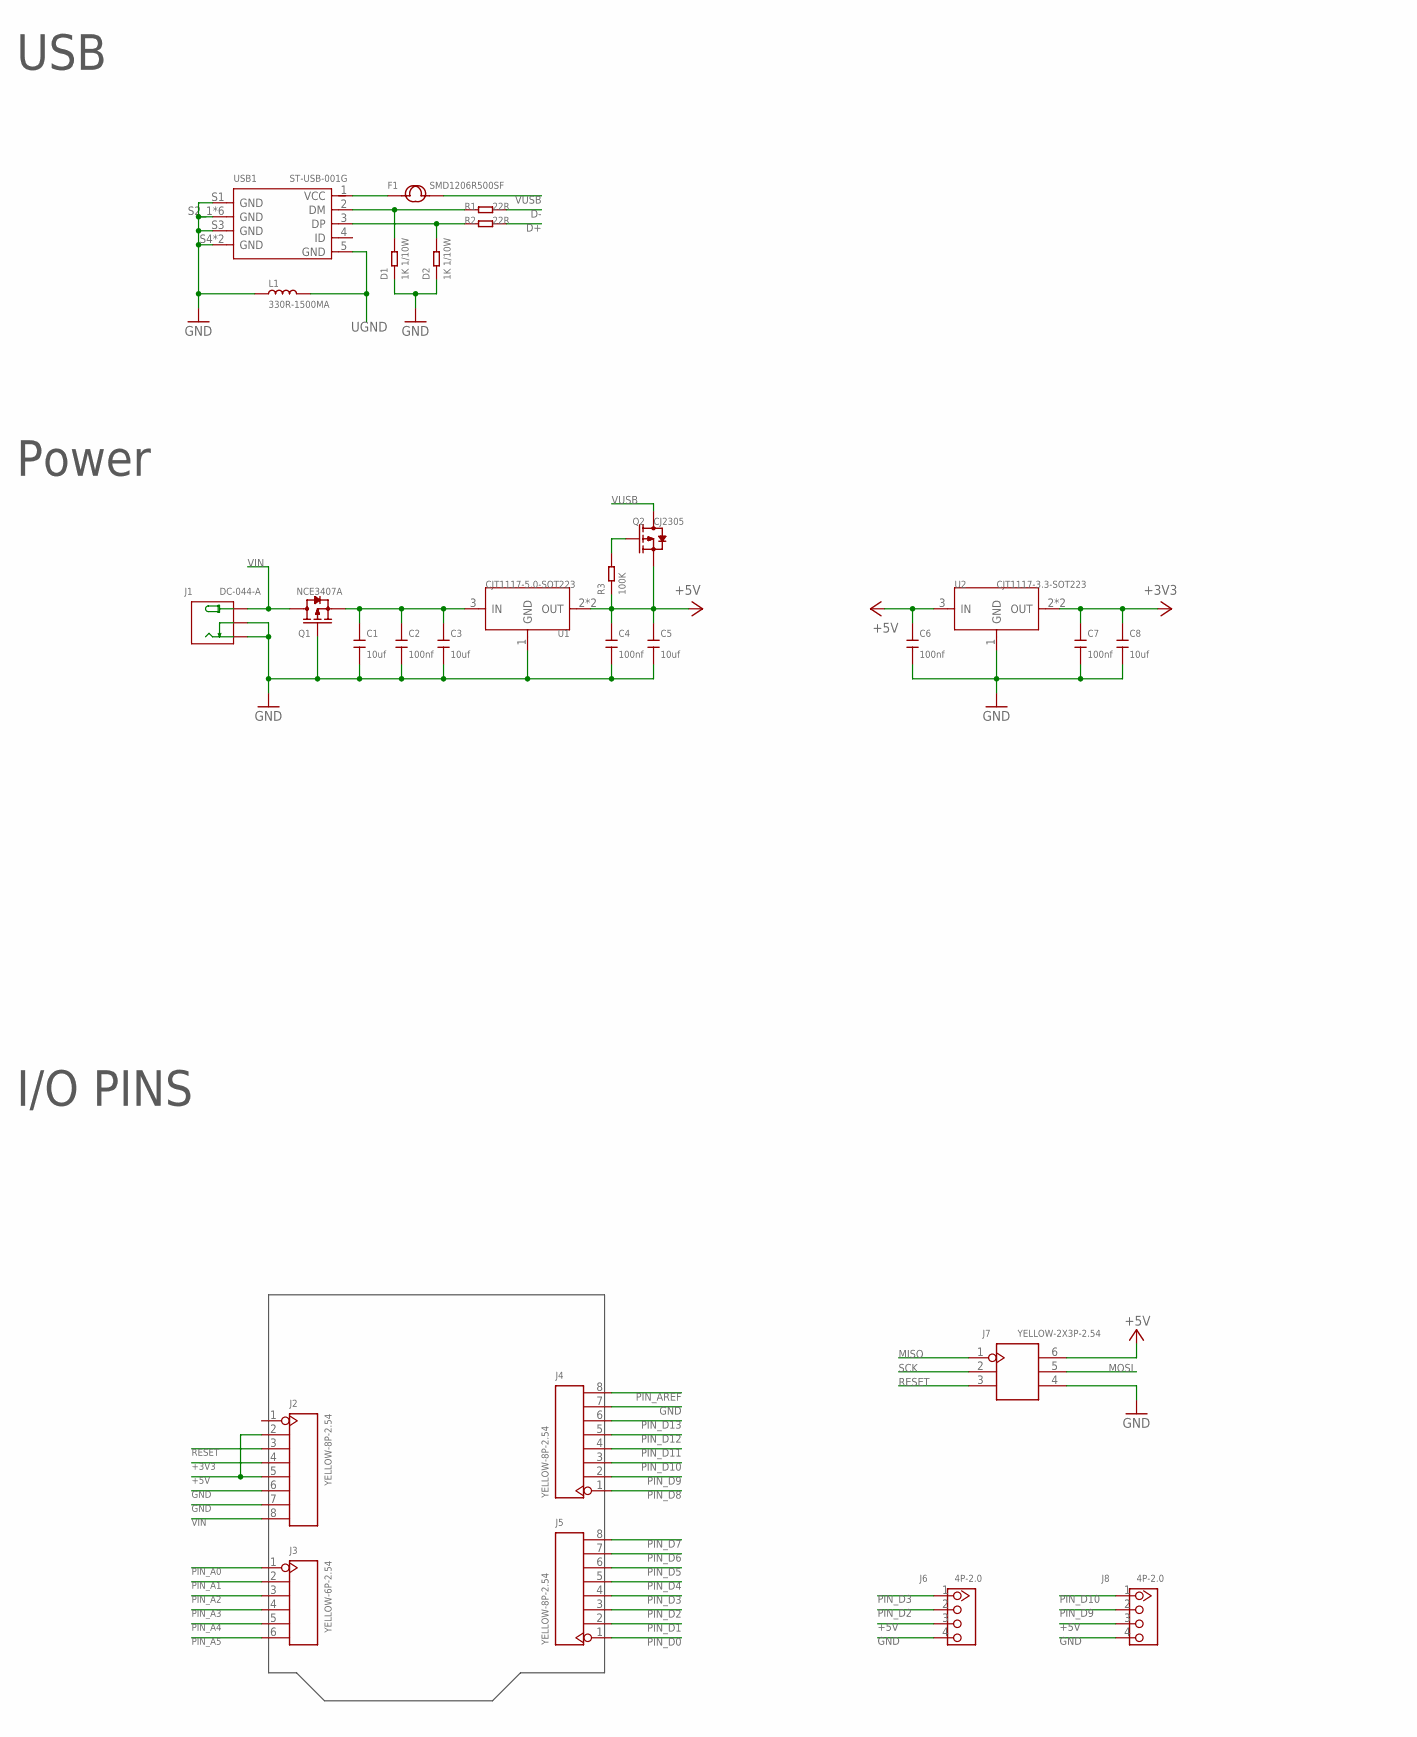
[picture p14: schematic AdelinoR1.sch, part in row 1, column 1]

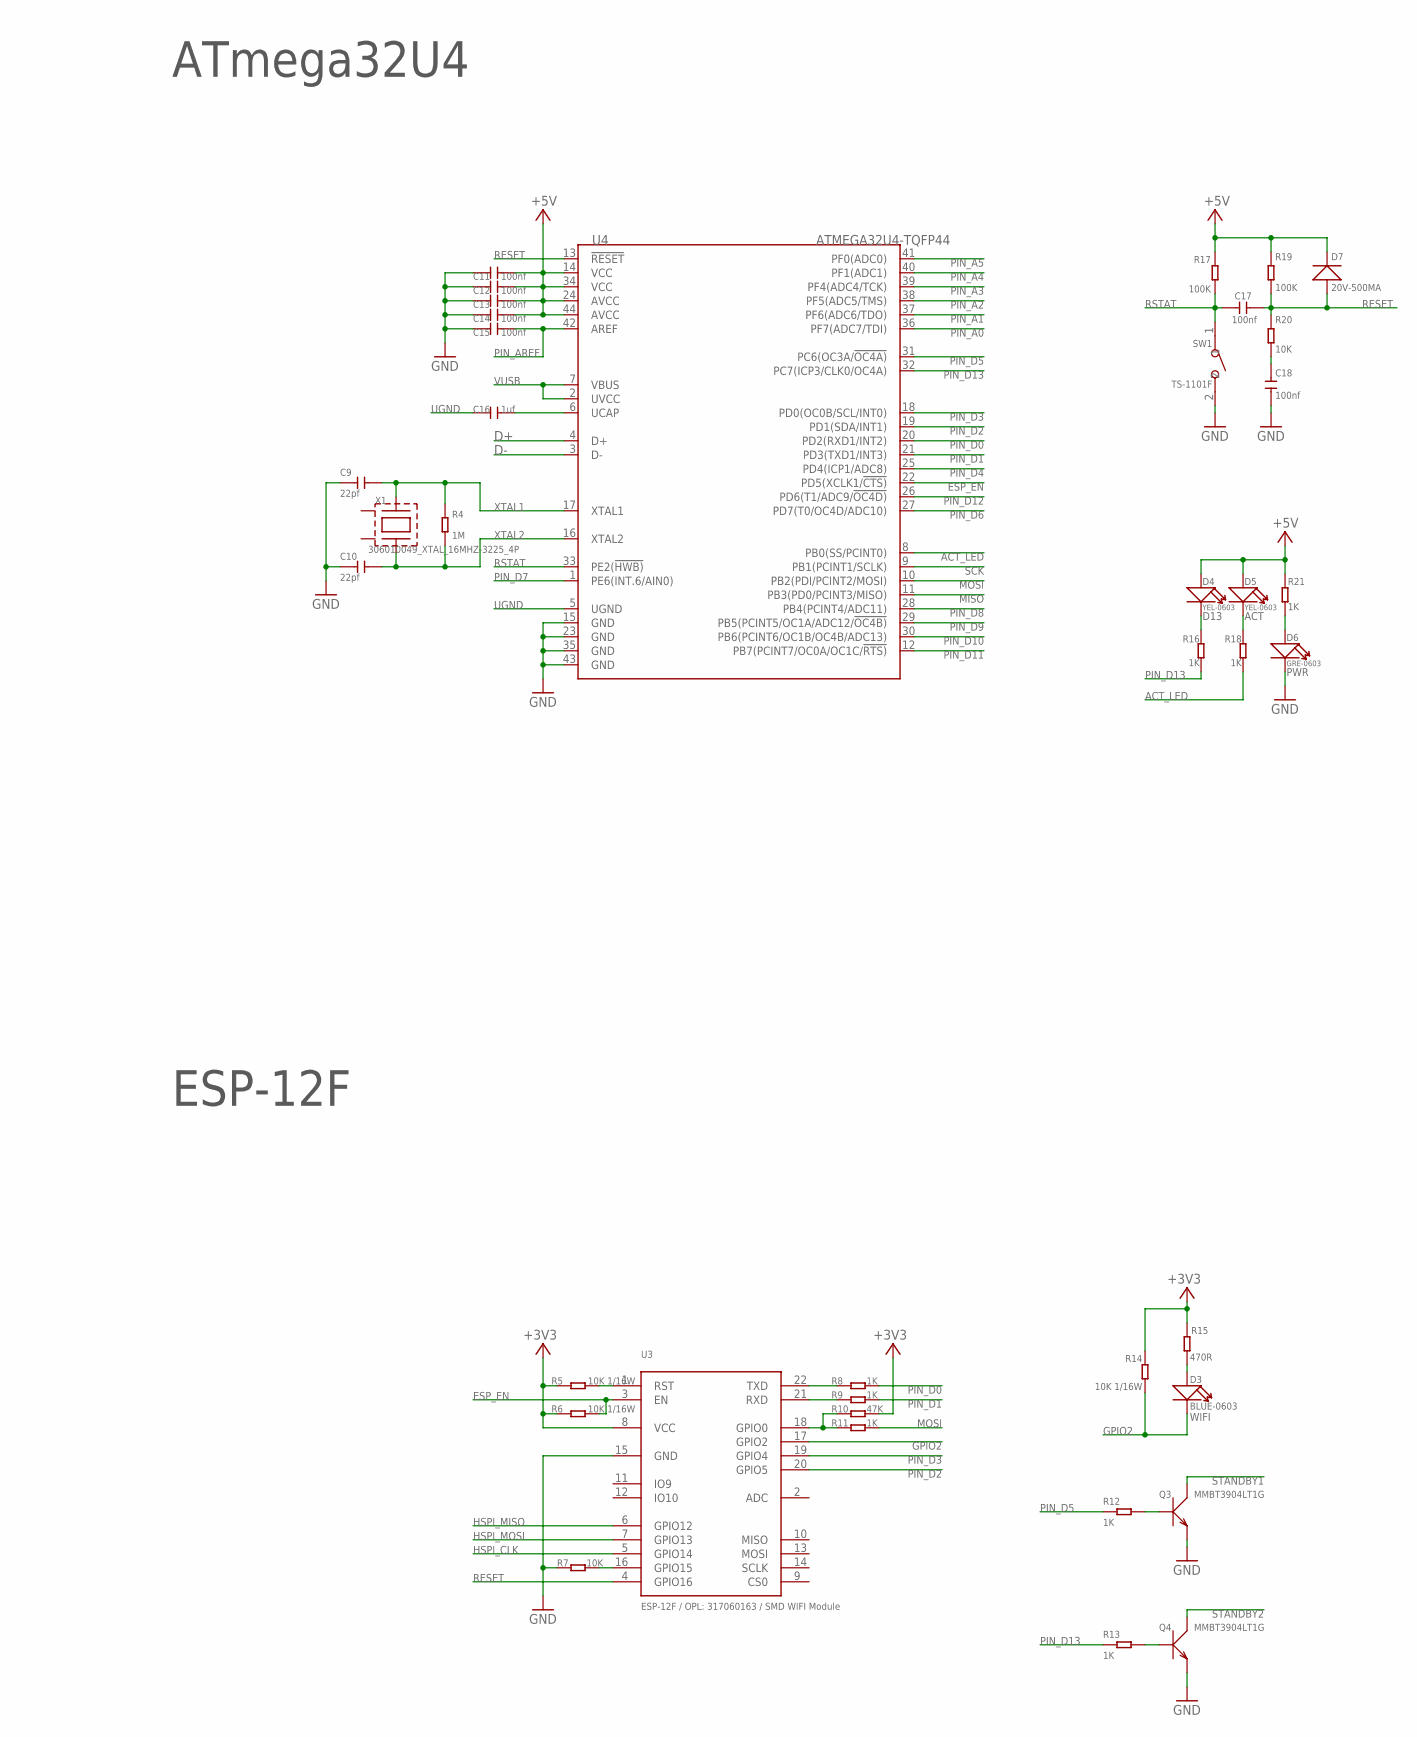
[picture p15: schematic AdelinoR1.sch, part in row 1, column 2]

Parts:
C1, C3, C5, C8: 10uf; C0805
C2, C4, C6, C7, C11, C12, C13, C14, C15, C17, C18: 100nf; C0402
C9, C10: 22pf; C0402
C16: 1uf; C0805
D1, D2: 1K 1/10W; D0603
D3: BLUE-0603; LED-0603
D4, D5: YEL-0603; LED-0603
D6: GRE-0603; LED-0603
D7: 20V-500MA; SOD-123
F1: SMD1206R500SF; F1206
J1: DC-044-A; DCJ3P-11.6X9.6X7.0MM
J2, J4, J5: YELLOW-8P-2.54; H8-2.54
J3: YELLOW-6P-2.54; H6-2.54
J6, J8: 4P-2.0; HW4-2.0
J7: YELLOW-2X3P-2.54; H2X3-2.54
L1: 330R-1500MA; L0805
Q1: NCE3407A; SOT-23
Q2: CJ2305; SOT-23
Q3, Q4: MMBT3904LT1G; SOT-23
R1, R2: 22R; R0402
R3, R17, R19: 100K; R0402
R4: 1M; R0402
R5, R6, R14: 10K 1/16W; R0402
R7, R20: 10K; R0402
R8, R9, R11, R12, R13, R16, R18, R21: 1K; R0402
R10: 47K; R0402
R15: 470R; R0402
SW1: TS-1101F; SW2-5.0-6.0X3.0X4.3MM
U1: CJT1117-5.0-SOT223; SOT-223
U2: CJT1117-3.3-SOT223; SOT-223
U3: ESP-12F / OPL: 317060163 / SMD WIFI Module; ESP-12F
U4: ATMEGA32U4-TQFP44; TQFP44-0.8-9.6X9.6MM
USB1: ST-USB-001G; MICRO-USB5+4P-SMD-0.65-B
X1: 306010049_XTAL_16MHZ-3225_4P; X3225_4P

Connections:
+3V3: C7.2, C8.2, J2.4, R5.1, R6.1, R10.2, R14.2, R15.2, U2.2 (OUT), U2.TER (OUT), U3.8 (VCC)
+5V: C4.2, C5.2, C6.2, C11.1, C12.1, C13.1, C14.1, D4.+, D5.+, D7.-, J2.2, J2.5, J6.3, J7.6, J8.3, Q2.2 (S), R3.1, R17.1, R19.2, R21.1, U1.2 (OUT), U1.TER (OUT), U2.3 (IN), U4.14 (VCC), U4.24 (AVCC), U4.34 (VCC), U4.44 (AVCC)
ACT_LED: R18.2, U4.8 (PB0(SS/PCINT0))
D+: R2.2, U4.4 (D+)
D-: R1.2, U4.3 (D-)
ESP_EN: R6.2, U3.3 (EN), U4.22 (PD5(XCLK1/!CTS))
GND: C1.1, C2.1, C3.1, C4.1, C5.1, C6.1, C7.1, C8.1, C9.1, C10.1, C11.2, C12.2, C13.2, C14.2, C15.2, C18.2, D1.1, D2.1, D6.-, J1.CDN1 (CDN), J1.CDN2 (CDN), J1.CDN3 (CDN), J1.CDN4 (CDN), J1.GND1 (-), J1.GND2 (-), J1.GND3 (-), J1.GND4 (-), J2.6, J2.7, J4.7, J6.4, J7.4, J8.4, L1.1, Q1.1 (G), Q3.2 (E), Q4.2 (E), R7.1, SW1.2, U1.1 (GND), U2.1 (GND), U3.15 (GND), U4.15 (GND), U4.23 (GND), U4.35 (GND), U4.43 (GND), USB1.S1 (GND), USB1.S2_1 (GND), USB1.S2_2 (GND), USB1.S2_3 (GND), USB1.S3 (GND), USB1.S4 (GND), USB1.S5_1 (GND), USB1.S5_2 (GND), USB1.S5_3 (GND), USB1.S6 (GND)
GND1: X1.P$2 (GND1)
GND2: X1.P$4 (GND2)
GPIO0: R10.1, R11.1, U3.18 (GPIO0)
GPIO2: D3.-, R14.1, U3.17 (GPIO2)
HSPI_CLK: U3.5 (GPIO14)
HSPI_MISO: U3.6 (GPIO12)
HSPI_MOSI: U3.7 (GPIO13)
MISO: J7.1, U4.11 (PB3(PD0/PCINT3/MISO))
MOSI: J7.5, R11.2, U4.10 (PB2(PDI/PCINT2/MOSI))
unnamed: D1.2, R1.1, USB1.2 (DM)
unnamed: D2.2, R2.1, USB1.3 (DP)
unnamed: Q2.1 (G), R3.2
unnamed: R7.2, U3.16 (GPIO15)
unnamed: D6.+, R21.2
unnamed: D5.-, R18.1
unnamed: C16.2, U4.6 (UCAP)
unnamed: D4.-, R16.1
unnamed: F1.1, USB1.1 (VCC)
unnamed: C1.2, C2.2, C3.2, Q1.2 (S), U1.3 (IN)
unnamed: D3.+, R15.1
unnamed: C18.1, R20.2
unnamed: R5.2, U3.1 (RST)
unnamed: Q3.1 (B), R12.2
unnamed: R8.1, U3.22 (TXD)
unnamed: R9.1, U3.21 (RXD)
unnamed: Q4.1 (B), R13.2
PIN_A0: J3.1, U4.36 (PF7(ADC7/TDI))
PIN_A1: J3.2, U4.37 (PF6(ADC6/TDO))
PIN_A2: J3.3, U4.38 (PF5(ADC5/TMS))
PIN_A3: J3.4, U4.39 (PF4(ADC4/TCK))
PIN_A4: J3.5, U4.40 (PF1(ADC1))
PIN_A5: J3.6, U4.41 (PF0(ADC0))
PIN_AREF: C15.1, J4.8, U4.42 (AREF)
PIN_D0: J5.1, R8.2, U4.20 (PD2(RXD1/INT2))
PIN_D1: J5.2, R9.2, U4.21 (PD3(TXD1/INT3))
PIN_D2: J5.3, J6.2, U3.20 (GPIO5), U4.19 (PD1(SDA/INT1))
PIN_D3: J5.4, J6.1, U3.19 (GPIO4), U4.18 (PD0(OC0B/SCL/INT0))
PIN_D4: J5.5, U4.25 (PD4(ICP1/ADC8))
PIN_D5: J5.6, R12.1, U4.31 (PC6(OC3A/!OC4A))
PIN_D6: J5.7, U4.27 (PD7(T0/OC4D/ADC10))
PIN_D7: J5.8, U4.1 (PE6(INT.6/AIN0))
PIN_D8: J4.1, U4.28 (PB4(PCINT4/ADC11))
PIN_D9: J4.2, J8.2, U4.29 (PB5(PCINT5/OC1A/ADC12/!OC4B))
PIN_D10: J4.3, J8.1, U4.30 (PB6(PCINT6/OC1B/OC4B/ADC13))
PIN_D11: J4.4, U4.12 (PB7(PCINT7/OC0A/OC1C/!RTS))
PIN_D12: J4.5, U4.26 (PD6(T1/ADC9/!OC4D))
PIN_D13: J4.6, R13.1, R16.2, U4.32 (PC7(ICP3/CLK0/OC4A))
RESET: C17.1, D7.+, J2.3, J7.3, R19.1, R20.1, U3.4 (GPIO16), U4.13 (!RESET)
RSTAT: C17.2, R17.2, SW1.1, U4.33 (PE2(!HWB))
SCK: J7.2, U4.9 (PB1(PCINT1/SCLK))
STANDBY1: Q3.3 (C)
STANDBY2: Q4.3 (C)
UGND: C16.1, L1.2, U4.5 (UGND), USB1.5 (GND)
VIN: J1.VCC1 (+), J1.VCC2 (+), J1.VCC3 (+), J1.VCC4 (+), J2.8, Q1.3 (D)
VUSB: F1.2, Q2.3 (D), U4.2 (UVCC), U4.7 (VBUS)
XTAL1: C9.2, R4.2, U4.17 (XTAL1), X1.P$1
XTAL2: C10.2, R4.1, U4.16 (XTAL2), X1.P$3

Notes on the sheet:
USB
Power
ATmega32U4
ESP-12F
I/O PINS

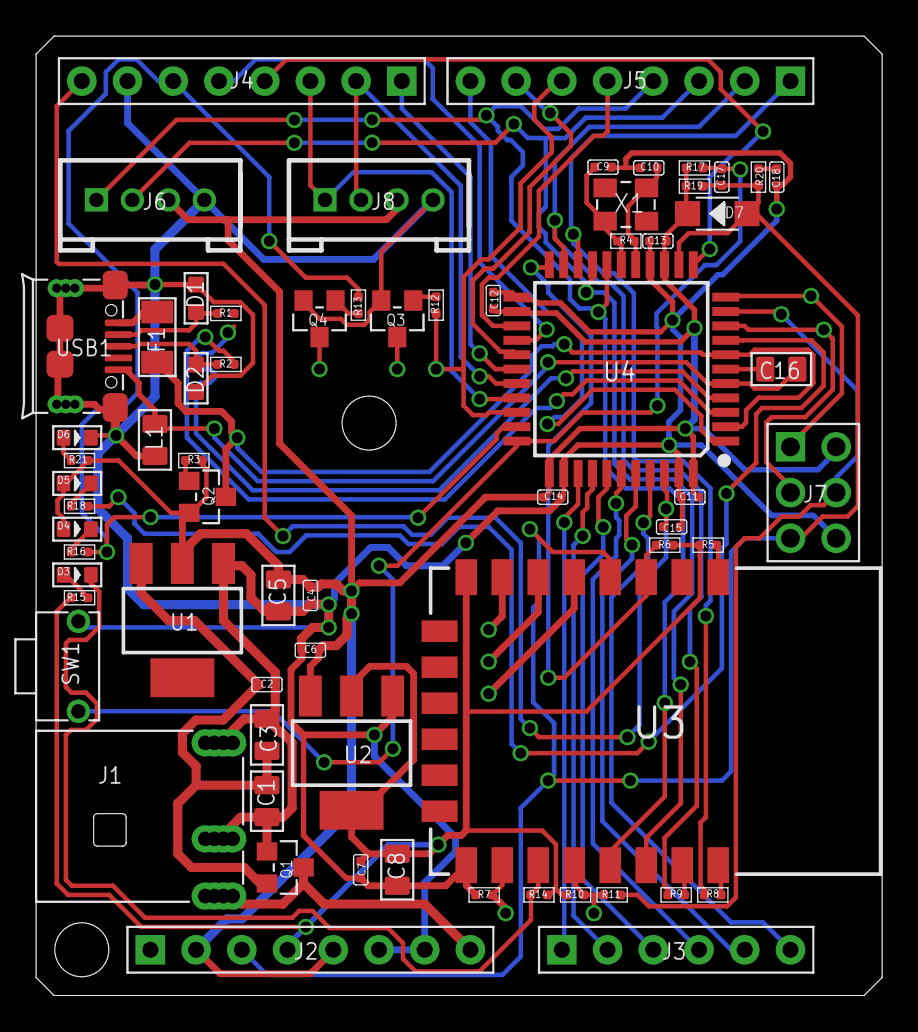
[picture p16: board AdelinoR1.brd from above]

Board: 2 copper layers, 47.0 x 53.3 mm, 67 parts (0 on the bottom side), 57 nets.

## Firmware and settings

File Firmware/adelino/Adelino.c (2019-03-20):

/*
             LUFA Library
     Copyright (C) Dean Camera, 2011.

  dean [at] fourwalledcubicle [dot] com
           www.lufa-lib.org
*/

/*
  Copyright 2011  Dean Camera (dean [at] fourwalledcubicle [dot] com)

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
  The author disclaim all warranties with regard to this
  software, including all implied warranties of merchantability
  and fitness.  In no event shall the author be liable for any
  special, indirect or consequential damages or any damages
  whatsoever resulting from loss of use, data or profits, whether
  in an action of contract, negligence or other tortious action,
  arising out of or in connection with the use or performance of
  this software.
*/

/*
  Copyright 2019  Marcond Marchi (marcond [at] gmail [dot] com)

  Permission to use, copy, modify, distribute, and sell this
  software and its documentation for any purpose is hereby granted
  without fee, provided that all copyright notices appear in
  all copies and that both that the copyright notices and this
  permission notice and warranty disclaimer appear in supporting
  documentation, and that the names of the authors not be used in
  advertising or publicity pertaining to distribution of the
  software without specific, written prior permission.

  The authors disclaim all warranties with regard to this
  software, including all implied warranties of merchantability
  and fitness.  In no event shall the authors be liable for any
  special, indirect or consequential damages or any damages
  whatsoever resulting from loss of use, data or profits, whether
  in an action of contract, negligence or other tortious action,
  arising out of or in connection with the use or performance of
  this software.
*/

/*
 * This file was heavily changed from Caterina.c available at:
 * https://github.com/arduino/ArduinoCore-avr/tree/master/bootloaders/caterina
 */

/** \file
 *
 *  Main source file for the CDC class bootloader. This file contains the
 *  complete bootloader logic.
 */

#include <avr/io.h>
#include <avr/wdt.h>
#include <avr/boot.h>
#include <avr/eeprom.h>
#include <avr/power.h>
#include <avr/interrupt.h>
#include <stdbool.h>

#include <LUFA/Drivers/USB/USB.h>

#include "Descriptors.h"
#include "Adelino.h"

#define MINIMAL_AVR109

// The very minimal needed for Avrdude to work
#ifdef MINIMAL_AVR109
  #ifndef NO_LOCK_BYTE_WRITE_SUPPORT
    #define NO_LOCK_BYTE_WRITE_SUPPORT
  #endif
  #ifndef NO_EEPROM_BYTE_SUPPORT
    #define NO_EEPROM_BYTE_SUPPORT
  #endif
  #ifndef NO_FLASH_BYTE_SUPPORT
    #define NO_FLASH_BYTE_SUPPORT
  #endif
#endif

/** Contains the current baud rate and other settings of the first virtual
 *  serial port. This must be retained as some operating systems will not open
 *  the port unless the settings can be set successfully.
 */
static CDC_LineEncoding_t LineEncoding =
{
    .BaudRateBPS = 0,
    .CharFormat  = CDC_LINEENCODING_OneStopBit,
    .ParityType  = CDC_PARITY_None,
    .DataBits    = 8
};

/** Current address counter. This stores the current address of the FLASH or
 *  EEPROM as set by the host, and is used when reading or writing to the AVRs
 *  memory (either FLASH or EEPROM depending on the issued command).
 */
static uint32_t CurrAddress;

// Calc how many 40ms ticks for the given millisecond interval
#define TICKS_MS(ms)              ((ms) / 50)

// Bootloader timeout timer
#define AVR_PROGRAMMER_TIMEOUT    TICKS_MS(3000)
#define ESP_PROGRAMMER_TIMEOUT    TICKS_MS(3000)
#define USB_COMM_TIMEOUT          TICKS_MS(250)

// uint16_t -> 3556, uint8_t -> 3504
static volatile uint8_t Timeout;
static volatile uint8_t rts_pulse;

// Bootloader actions
#define ACT_STAY_INTO_BOOTLOADER  TICKS_MS(1000)
#define ACT_BOOTLOADER_TIMEOUT    TICKS_MS(8000)
#define ACT_RESET_ESP8266         TICKS_MS(3000)
#define ACT_RECONFIGURE_ESP8266   TICKS_MS(5000)
#define ACT_FACTORY_DEFAULTS      TICKS_MS(5000)

// Bootloader status
static uint8_t boot_mode;
#define BM_NORMAL_BOOT            '0'
#define BM_KEEP_BOOTLOADER        '1'
#define BM_ESP_RESET              'R'
#define BM_ESP_RECONFIGURE        'E'
#define BM_ESP_FACTORY            'F'

// Serial baud divisor
#define SERIAL_2X_UBBRVAL(Baud) ((((F_CPU / 8) + (Baud / 2)) / (Baud)) - 1)

#ifndef BAUD_RATE
//#define BAUD_RATE   74880L        // ESP8266 Boot post
#define BAUD_RATE   115200L
#endif

uint16_t bootKey = 0x7777;
volatile uint16_t *const bootKeyPtr = (volatile uint16_t *)0x0800;

__attribute__((noreturn))
__attribute__((noinline))
__attribute__((naked))
static void start_sketch (void)
{
    cli ();

    // Disable USART1
    UCSR1B = 0;

    // Undo TIMER1 setup and clear the count before running the sketch
    TIMSK1 = 0;
    TCCR1B = 0;
    TCNT1H = 0;         // 16-bit write to TCNT1 requires high byte be written first
    TCNT1L = 0;

    // Relocate the interrupt vector table to the application section
    MCUCR = (1 << IVCE);
    MCUCR = 0;

    L_LED_OFF();
    ACT_LED_OFF();

    // jump to beginning of application space
    __asm__ volatile("jmp 0x0000");
}

static uint16_t led_counter;
static uint8_t led_control = 0xff;
static uint8_t leds_enabled;

static void CDC_Task (void);

static void run_tasks (void)
{
    CDC_Task ();

    if (leds_enabled)
    {
        if (led_control == 0xff)
        {
            // Breathing animation on ACT/D13 LED indicates bootloader is running
            led_counter++;
            uint8_t p = led_counter >> 8;
            if (p > 127)
            {
                p = 254-p;
            }
            p += p;
            if (((uint8_t)led_counter) > p)
            {
                L_LED_OFF();
                ACT_LED_ON();
            }
            else
            {
                L_LED_ON();
                ACT_LED_OFF();
            }
        }
        else if (led_counter > led_control)
        {
            // Blinking animation on ACT/D13 indicates ESP8266 actions
            led_counter = 0;
            L_LED_TOGGLE();
            ACT_LED_TOGGLE();
        }
    }
}

__attribute__((noinline))
static void putch (char ch)
{
    while (!(UCSR1A & _BV(UDRE1)));
    UDR1 = ch;
}

static uint8_t buffer [256];        // This buffer MUST BE 256 bytes long !!!
static volatile uint8_t buffer_in;  // It is so because we use single bytes as
static uint8_t buffer_out; // indexes, with the natural range 0..255

ISR(USART1_RX_vect, ISR_BLOCK)
{
    uint8_t ch = UDR1;
    uint8_t next = buffer_in + 1;

    // A very simple circular buffer
    if (next != buffer_out)
    {
        buffer [buffer_in] = ch;
        buffer_in = next;
    }
}

__attribute__((noinline))
static uint8_t rstat (void)
{
    // Read the reset switch preserving the port configuration afterwards
    cli ();
    uint8_t save_PORTD = PORTD;
    PORTD |= _BV(5); // Pull up
    uint8_t save_DDRD = DDRD;
    DDRD &= ~_BV(5); // PD5 -> input
    __asm__ volatile ("rjmp .+0");      // Discard small diode capacitance
    uint8_t stat = !(PIND & _BV(5));
    PORTD = save_PORTD;
    DDRD = save_DDRD;
    sei ();
    return (stat);
}

static void reset_esp (uint8_t program_mode)
{
    // GPIO15 is also HSPI_CS, which is connected to SS on
    // AVR SPI; so we MUST ensure GPIO15 LOW for proper boot.
    PORTB &= ~_BV(0); // GPIO15 => LOW
    DDRB |= _BV(0); // PB0 (SS) => OUTPUT

    // D13 is also used to drive GPIO0, which is the main
    // boot mode selector. GPIO0 HIGH for normal boot, GPIO0
    // LOW to enter ROM bootloader.
    if (program_mode)
    {
        // Enter ROM bootloader
        PORTC &= ~_BV(7);
    }
    else
    {
        // Normal boot
        PORTC |= _BV(7);
    }
    DDRC |= _BV(7);

    // We set pin direction only after setting value
    // because if it's not configured yet (hi-z) it
    // will be pulled up. If we are setting it HIGH
    // and configure direction first, we may get a
    // unintended short LOW pulse. Therefore,
    // direction is set only after the intended level
    // is set.

    // Set CHIP_EN low
    PORTE &= ~_BV(2); // PE2 => LOW
    DDRE |= _BV(2); // PE2 => OUTPUT

    // Keep it low at least 1ms for a clean ESP8266 reset
    _delay_ms (1);

    // Set CHIP_EN high
    PORTE |= _BV(2); // PE2 => HIGH
}

__attribute__((noinline))
static void reset_esp_and_wait (uint8_t program_mode)
{
    leds_enabled = 0;
    ACT_LED_ON();
    L_LED_ON();
    reset_esp (program_mode);
    for (Timeout = TICKS_MS(350); Timeout; USB_USBTask ());
    leds_enabled = 1;

    // Ring buffer is now empty again
    buffer_in = buffer_out = 0;
}

/** Configures all hardware required for the bootloader. */
static void setup_hardware (void)
{
    // Disable watchdog if enabled by bootloader/fuses
    MCUSR &= ~(1 << WDRF);

    // Low-carbs wdt_disable()
    WDTCSR = _BV(WDE) | _BV(WDCE);
    WDTCSR = 0;

    // Low-carbs disable clock division
    CLKPR = _BV(CLKPCE);
    CLKPR = clock_div_1;

    // Relocate the interrupt vector table to the bootloader section
    MCUCR = (1 << IVCE);
    MCUCR = (1 << IVSEL);

    LED_SETUP();
    L_LED_OFF();
    ACT_LED_OFF();

    // Init USART1
    UBRR1  = SERIAL_2X_UBBRVAL(BAUD_RATE);
    UCSR1A = _BV(U2X1);                                 // Double speed mode
    UCSR1C = _BV(UCSZ10) | _BV(UCSZ11);                 // Async 8 N 1
    UCSR1B = _BV(RXEN1) | _BV(TXEN1) | _BV(RXCIE1);     // Enable tx and rx

    // Initialize TIMER1 to handle bootloader timeout and LED tasks.
    // The timer is set to 20Hz or once every 50ms, so we can use a single byte
    // for timeout counting (0..254 -> 254 x 50ms = 12700ms or 12.7s).
    // This interrupt is disabled selectively when doing memory reading, erasing,
    // or writing since SPM has tight timing requirements.
    OCR1A = 12499;
    TIMSK1 = _BV(OCIE1A);		                    // enable timer 1 output compare A match interrupt
    TCCR1B = _BV(CS11) | _BV(CS10) | _BV(WGM12);    // 1/64 prescaler on timer 1 input

    // Initialize USB Subsystem
    USB_Init ();

    // Enable global interrupts so that the USB stack can function
    sei ();
}

/** Check whether reset button is pressed during 'ticks' interval */
static uint8_t check_reset (uint8_t ticks)
{
    for (Timeout = ticks; Timeout && rstat (); run_tasks ());
    return (rstat ());
}

/** Main program entry point. This routine configures the hardware required by
 *  the bootloader, then continuously runs the bootloader processing routine
 *  until it times out or is instructed to exit.
 */
int main (void)
{
    // Save the value of the boot key memory before it is overwritten
    uint16_t bootKeyPtrVal = *bootKeyPtr;
    *bootKeyPtr = 0;

    // TODO: PUT THESE INITS ASIDE

    // Check the reason for the reset so we can act accordingly
    uint8_t  mcusr_state = MCUSR;       // store the initial state of the Status register
    MCUSR = 0;                          // clear all reset flags	

    // Watchdog may be configured with a 15 ms period so must disable it before going any further
    wdt_disable ();

    uint8_t sketch_available = pgm_read_word(0) != 0xFFFF;

    if (mcusr_state & (1<<EXTRF))
    {
        // External reset -  we should continue to self-programming mode.
    }
    else if ((mcusr_state & (1<<PORF)) && sketch_available)
    {
        // After a power-on reset skip the bootloader and jump straight to sketch 
        // if one exists.
        start_sketch ();
    } 
    else if ((mcusr_state & (1<<WDRF)) && (bootKeyPtrVal != bootKey) && sketch_available)
    {
        // If it looks like an "accidental" watchdog reset then start the sketch.
        start_sketch ();
    }

    // Setup hardware required for the bootloader
    setup_hardware ();

    // Should we stay inside the bootloader?
    if (check_reset (ACT_STAY_INTO_BOOTLOADER) || !sketch_available)
    {
        // Breathing led
        boot_mode = leds_enabled = BM_KEEP_BOOTLOADER;

        // Check for ESP8266 reset
        if (check_reset (ACT_RESET_ESP8266))
        {
            // Reset ESP8266
            boot_mode = BM_ESP_RESET;
            reset_esp_and_wait (false);

            // Check for ESP8266 reconfiguration (slow blinking)
            if (check_reset (ACT_RECONFIGURE_ESP8266))
            {
                // Reconfiguration is being requested
                boot_mode = BM_ESP_RECONFIGURE;
                led_control = TICKS_MS(200);

                // Check for ESP8266 factory defaults reset
                if (check_reset (ACT_FACTORY_DEFAULTS))
                {
                    // Factory reset is being requested
                    boot_mode = BM_ESP_FACTORY;

                    // Very fast blinking
                    led_control = 1;
                }
            }
        }
    }
    else
    {
        // The normal boot must have a normal bootloader timeout
        boot_mode = leds_enabled = BM_NORMAL_BOOT;
        Timeout = ACT_BOOTLOADER_TIMEOUT;
    }

    // Keep the bootloader running if:
    //
    // a) The boot mode is any other than normal;
    //    or
    // b) The boot mode is normal, but timeout is still running.
    //
    while (boot_mode != BM_NORMAL_BOOT || Timeout)
    {
        run_tasks ();
    }

    // Disconnect from the host - USB interface will be reset later along with the AVR
    USB_Detach();

    // Jump to beginning of application space to run the sketch - do not reset
    start_sketch ();
}

ISR(TIMER1_COMPA_vect, ISR_BLOCK)
{
    if (leds_enabled)
    {
        led_counter++;
    }

    if (Timeout)
    {
        Timeout--;
    }
}

//-----------------------------------------------------------------------------
// USB FUNCTIONS
//-----------------------------------------------------------------------------

/** Event handler for the USB_ConfigurationChanged event. This configures the
 *  device's endpoints ready to relay data to and from the attached USB host.
 */
void EVENT_USB_Device_ConfigurationChanged (void)
{
    // Setup CDC Notification, Rx and Tx Endpoints
    Endpoint_ConfigureEndpoint(CDC_NOTIFICATION_EPNUM, EP_TYPE_INTERRUPT,
                               ENDPOINT_DIR_IN, CDC_NOTIFICATION_EPSIZE,
                               ENDPOINT_BANK_SINGLE);

    Endpoint_ConfigureEndpoint(CDC_TX_EPNUM, EP_TYPE_BULK,
                               ENDPOINT_DIR_IN, CDC_TXRX_EPSIZE,
                               ENDPOINT_BANK_SINGLE);

    Endpoint_ConfigureEndpoint(CDC_RX_EPNUM, EP_TYPE_BULK,
                               ENDPOINT_DIR_OUT, CDC_TXRX_EPSIZE,
                               ENDPOINT_BANK_SINGLE);
}

/** Event handler for the USB_ControlRequest event. This is used to catch and
 *  process control requests sent to the device from the USB host before
 *  passing along unhandled control requests to the library for processing
 *  internally.
 */
void EVENT_USB_Device_ControlRequest (void)
{
    // Ignore any requests that aren't directed to the CDC interface
    if ((USB_ControlRequest.bmRequestType & (CONTROL_REQTYPE_TYPE | CONTROL_REQTYPE_RECIPIENT)) !=
        (REQTYPE_CLASS | REQREC_INTERFACE))
    {
        return;
    }

    // Process CDC specific control requests
    switch (USB_ControlRequest.bRequest)
    {
        case CDC_REQ_GetLineEncoding:
        {
            if (USB_ControlRequest.bmRequestType == (REQDIR_DEVICETOHOST | REQTYPE_CLASS | REQREC_INTERFACE))
            {
                Endpoint_ClearSETUP ();

                // Write the line coding data to the control endpoint
                Endpoint_Write_Control_Stream_LE (&LineEncoding, sizeof(CDC_LineEncoding_t));
                Endpoint_ClearOUT ();
            }
            break;
        }
        case CDC_REQ_SetLineEncoding:
        {
            if (USB_ControlRequest.bmRequestType == (REQDIR_HOSTTODEVICE | REQTYPE_CLASS | REQREC_INTERFACE))
            {
                Endpoint_ClearSETUP ();

                // Read the line coding data in from the host into the global struct
                Endpoint_Read_Control_Stream_LE (&LineEncoding, sizeof(CDC_LineEncoding_t));
                Endpoint_ClearIN ();
            }
            break;
        }
        case CDC_REQ_SetControlLineState:
        {
            if (USB_ControlRequest.bmRequestType == (REQDIR_HOSTTODEVICE | REQTYPE_CLASS | REQREC_INTERFACE))
            {
                Endpoint_ClearSETUP ();
                Endpoint_ClearStatusStage ();

                // Let us know if we had a pulse on RTS
                rts_pulse |= USB_ControlRequest.wValue & CDC_CONTROL_LINE_OUT_RTS;
            }
            break;
        }
    }
}

static uint8_t usb_byte_available (void)
{
    // This is a strategic place to call the usb tasks, since checking
    // for ready bytes is perhaps the top task inside loops
    USB_USBTask ();

    // Select the OUT endpoint so that the next data byte can be read
    Endpoint_SelectEndpoint (CDC_RX_EPNUM);

    if (Endpoint_IsOUTReceived ())
    {
        if (Endpoint_BytesInEndpoint ())
        {
            return (true);
        }
        Endpoint_ClearOUT ();
    }
    return (false);
}

static uint8_t endpoint_detached (void)
{
    return (!Timeout || USB_DeviceState == DEVICE_STATE_Unattached);
}

/** Retrieves the next byte from the host in the CDC data OUT endpoint, and
 *  clears the endpoint bank if needed to allow reception of the next data
 *  packet from the host.
 *
 *  \return Next received byte from the host in the CDC data OUT endpoint
 */
static uint8_t usb_read_byte (void)
{
    while (!usb_byte_available ())
    {
        if (endpoint_detached ())
        {
            return (0);
        }
    }

    // Fetch the next byte from the OUT endpoint
    return (Endpoint_Read_8 ());
}

static void _usb_flush_endpoint (void)
{
    // Send the endpoint data to the host
    Endpoint_ClearIN ();

    // Wait until the data has been sent to the host
    while (!Endpoint_IsINReady ())
    {
        if (endpoint_detached ())
        {
            return;
        }
    }
}

static void usb_flush (void)
{
    // Select the IN endpoint
    Endpoint_SelectEndpoint (CDC_TX_EPNUM);

    // Do we have bytes to flush actually?
    if (!Endpoint_BytesInEndpoint ())
    {
        return;
    }

    // Is the endpoint full?
    if (!Endpoint_IsReadWriteAllowed ())
    {
        // If a full endpoint's worth of data was sent, we need to send
        // an empty packet afterwards to signal end of transfer
        _usb_flush_endpoint ();
    }

    // Send the endpoint data to the host and wait
    // until the data has been sent to the host
    _usb_flush_endpoint ();
}

/** Writes the next response byte to the CDC data IN endpoint, and sends the
 *  endpoint back if needed to free up the bank when full ready for the next
 *  byte in the packet to the host.
 *
 *  \param[in] Response  Next response byte to send to the host
 */
static void usb_write_byte (const uint8_t Response)
{
    USB_USBTask ();

    // Select the IN endpoint so that the next data byte can be written
    Endpoint_SelectEndpoint (CDC_TX_EPNUM);

    // If IN endpoint full, clear it and wait until ready
    // for the next packet to the host
    if (!Endpoint_IsReadWriteAllowed ())
    {
        _usb_flush_endpoint ();
    }

    // Write the next byte to the IN endpoint
    Endpoint_Write_8 (Response);
}

//-----------------------------------------------------------------------------
// AVR PROGRAMMING FUNCTIONS
//-----------------------------------------------------------------------------
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

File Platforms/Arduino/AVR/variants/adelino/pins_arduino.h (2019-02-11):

/*
  pins_arduino.h - Pin definition functions for Arduino
  Part of Arduino - http://www.arduino.cc/

  Copyright (c) 2007 David A. Mellis

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
  You should have received a copy of the GNU Lesser General
  Public License along with this library; if not, write to the
  Free Software Foundation, Inc., 59 Temple Place, Suite 330,
  Boston, MA  02111-1307  USA
*/

#ifndef Pins_Arduino_h
#define Pins_Arduino_h

#include <avr/pgmspace.h>

// Workaround for wrong definitions in "iom32u4.h".
// This should be fixed in the AVR toolchain.
#undef UHCON
#undef UHINT
#undef UHIEN
#undef UHADDR
#undef UHFNUM
#undef UHFNUML
#undef UHFNUMH
#undef UHFLEN
#undef UPINRQX
#undef UPINTX
#undef UPNUM
#undef UPRST
#undef UPCONX
#undef UPCFG0X
#undef UPCFG1X
#undef UPSTAX
#undef UPCFG2X
#undef UPIENX
#undef UPDATX
#undef TCCR2A
#undef WGM20
#undef WGM21
#undef COM2B0
#undef COM2B1
#undef COM2A0
#undef COM2A1
#undef TCCR2B
#undef CS20
#undef CS21
#undef CS22
#undef WGM22
#undef FOC2B
#undef FOC2A
#undef TCNT2
#undef TCNT2_0
#undef TCNT2_1
#undef TCNT2_2
#undef TCNT2_3
#undef TCNT2_4
#undef TCNT2_5
#undef TCNT2_6
#undef TCNT2_7
#undef OCR2A
#undef OCR2_0
#undef OCR2_1
#undef OCR2_2
#undef OCR2_3
#undef OCR2_4
#undef OCR2_5
#undef OCR2_6
#undef OCR2_7
#undef OCR2B
#undef OCR2_0
#undef OCR2_1
#undef OCR2_2
#undef OCR2_3
#undef OCR2_4
#undef OCR2_5
#undef OCR2_6
#undef OCR2_7

#define NUM_DIGITAL_PINS  31
#define NUM_ANALOG_INPUTS 12

// Adelino is similar to Leonardo, but have only
// a single LED to indicate TX and RX activity.
#define TX_RX_LED_INIT  DDRB |= (1<<0), RXLED0
#define TXLED0          RXLED0
#define TXLED1          RXLED1
#define RXLED0          PORTB &= ~(1<<0)
#define RXLED1          PORTB |= (1<<0)

#define PIN_WIRE_SDA         (2)
#define PIN_WIRE_SCL         (3)

static const uint8_t SDA = PIN_WIRE_SDA;
static const uint8_t SCL = PIN_WIRE_SCL;

#define LED_BUILTIN 13
#define LED_BUILTIN_RX 17
#define LED_BUILTIN_TX 30

// Map SPI port to 'new' pins D14..D17
#define PIN_SPI_SS    (17)
#define PIN_SPI_MOSI  (16)
#define PIN_SPI_MISO  (14)
#define PIN_SPI_SCK   (15)

static const uint8_t SS   = PIN_SPI_SS;
static const uint8_t MOSI = PIN_SPI_MOSI;
static const uint8_t MISO = PIN_SPI_MISO;
static const uint8_t SCK  = PIN_SPI_SCK;

// Mapping of analog pins as digital I/O
// A6-A11 share with digital pins
#define PIN_A0   (18)
#define PIN_A1   (19)
#define PIN_A2   (20)
#define PIN_A3   (21)
#define PIN_A4   (22)
#define PIN_A5   (23)
#define PIN_A6   (24)
#define PIN_A7   (25)
#define PIN_A8   (26)
#define PIN_A9   (27)
#define PIN_A10  (28)
#define PIN_A11  (29)

static const uint8_t A0 = PIN_A0;
static const uint8_t A1 = PIN_A1;
static const uint8_t A2 = PIN_A2;
static const uint8_t A3 = PIN_A3;
static const uint8_t A4 = PIN_A4;
static const uint8_t A5 = PIN_A5;
static const uint8_t A6 = PIN_A6;	// D4
static const uint8_t A7 = PIN_A7;	// D6
static const uint8_t A8 = PIN_A8;	// D8
static const uint8_t A9 = PIN_A9;	// D9
static const uint8_t A10 = PIN_A10;	// D10
static const uint8_t A11 = PIN_A11;	// D12

#define digitalPinToPCICR(p)    ((((p) >= 8 && (p) <= 11) || ((p) >= 14 && (p) <= 17) || ((p) >= A8 && (p) <= A10)) ? (&PCICR) : ((uint8_t *)0))
#define digitalPinToPCICRbit(p) 0
#define digitalPinToPCMSK(p)    ((((p) >= 8 && (p) <= 11) || ((p) >= 14 && (p) <= 17) || ((p) >= A8 && (p) <= A10)) ? (&PCMSK0) : ((uint8_t *)0))
#define digitalPinToPCMSKbit(p) ( ((p) >= 8 && (p) <= 11) ? (p) - 4 : ((p) == 14 ? 3 : ((p) == 15 ? 1 : ((p) == 16 ? 2 : ((p) == 17 ? 0 : (p - A8 + 4))))))

//	__AVR_ATmega32U4__ has an unusual mapping of pins to channels
extern const uint8_t PROGMEM analog_pin_to_channel_PGM[];
#define analogPinToChannel(P)  ( pgm_read_byte( analog_pin_to_channel_PGM + (P) ) )

#define digitalPinHasPWM(p)         ((p) == 3 || (p) == 5 || (p) == 6 || (p) == 9 || (p) == 10 || (p) == 11 || (p) == 13)

#define digitalPinToInterrupt(p) ((p) == 0 ? 2 : ((p) == 1 ? 3 : ((p) == 2 ? 1 : ((p) == 3 ? 0 : ((p) == 7 ? 4 : NOT_AN_INTERRUPT)))))

#ifdef ARDUINO_MAIN

// On the Arduino board, digital pins are also used
// for the analog output (software PWM).  Analog input
// pins are a separate set.
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

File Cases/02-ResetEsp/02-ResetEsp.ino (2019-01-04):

// Reset ESP-8266 using HWB.
// 
// It uses reset switch status to decide whether it will
// reset ESP or not. To test, press Adelino reset switch. 
// The sketch will blink 3 times before acquiring the reset 
// switch status. If the reset switch is kept pressed, the
// ESP-8266 will be reset by asserting HWB/PE2 low for 10ms.

int rstat ()
{
  // Read the reset switch preserving the port configuration afterwards
  unsigned char save_DDRD = DDRD;
  unsigned char save_PORTD = PORTD;
  cli ();
  DDRD &= ~_BV(5); // PD5 -> input
  PORTD |= _BV(5); // Pull up
  int stat = !(PIND & _BV(5));
  PORTD = save_PORTD;
  DDRD = save_DDRD;
  sei ();
  return (stat);
}

// Set the logic level on CHIP_EN line, which is 
// connected to HWB (PE2) from ATmega32U4.
int espen (int level)
{
  if (level)
  {
    PORTE |= _BV(2); // PE2 => HIGH
  }
  else
  {
    PORTE &= ~_BV(2); // PE2 => LOW
  }

  // We set pin direction only after setting value
  // because if it's not configured yet (hi-z) it 
  // will be pulled up. If we are setting it HIGH
  // and configure direction first, we may get a
  // unintended short LOW pulse. Therefore, 
  // direction is set only after the intended level 
  // is set.
  DDRE |= _BV(2); // PE2 => OUTPUT
}

void setup ()
{
  // GPIO15 is also HSPI_CS, which is connected to SS on
  // AVR SPI; so we MUST ensure GPIO15 LOW for proper boot.
  pinMode (PIN_SPI_SS, OUTPUT);

  // D13 is also used to drive GPIO0, which is the main
  // boot mode selector. GPIO0 HIGH for normal boot, GPIO0
  // LOW to enter ROM bootloader.
  pinMode (LED_BUILTIN, OUTPUT);

  for (int i = 0; i < 3; i++)
  {
    digitalWrite (LED_BUILTIN, HIGH);
    delay(500);
    digitalWrite (LED_BUILTIN, LOW);
    delay(500);
  }

  //===========
  // Reset ESP
  //===========

  if (rstat ())
  {
    // Enter ROM bootloader
    digitalWrite (LED_BUILTIN, LOW); // GPIO0 => LOW
  }
  else
  {
    // Normal boot
    digitalWrite (LED_BUILTIN, HIGH); // GPIO0 => HIGH
  }
  
  digitalWrite (PIN_SPI_SS, LOW); // GPIO15 => LOW
  delay (10);
  espen (LOW); // CHIP_EN => LOW
  delay (50);
  espen (HIGH); // CHIP_EN => HIGH
  delay (250);
}

void loop ()
{
  // put your main code here, to run repeatedly
}

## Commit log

2018-10-02 Add Adelino R1 schematics (wip).
    [AdelinoR1.sch]
2018-10-03 ATmega32u4 wiring and some pinouts.
    [AdelinoR1.sch]
2018-10-03 Arduino-compatible pinout.
    [AdelinoR1.sch]
2018-10-03 Add technical refs; ESP8266 wip.
    [AdelinoR1.sch]
2018-10-04 Base circuit finished; ERC pass.
    [AdelinoR1.sch]
2018-10-05 Fix R7 too strong pull-up for GPIO0.
    [AdelinoR1.sch]
2018-10-11 Change reset switch to be readable.
    [AdelinoR1.sch]
2018-10-14 Adelino X1 prototype pending revision.
    [AdelinoR1.brd, AdelinoR1.sch]
2018-10-15 Add MOSI->GPIO0 connection.
    [AdelinoR1.brd]
2018-10-15 Add reset switch test case.
2018-10-15 Add ESP reset using SCK.
    [02-ResetEsp.ino]
2018-10-16 Renumbered parts.
    [AdelinoR1.brd, AdelinoR1.sch]
2018-10-16 Now SCK drives CHIP_EN instead of RST; RST pulled high using 4K7.
    [AdelinoR1.brd, AdelinoR1.sch]
2018-10-17 Change ACT_LED to PB0; change ESP_EN to PD5; change WIFI led to GPIO2.
    [AdelinoR1.brd, AdelinoR1.sch]
2018-10-18 Adelino X1 final design.
    [AdelinoR1.brd, AdelinoR1.sch]
2018-10-18 Add spare vias for SPI.
    [AdelinoR1.brd, AdelinoR1.sch]
2018-11-05 Add Coraline bootloader wip.
    [ConfiguringApps.txt]
2018-11-12 Fix component names placement for assembly.
    [AdelinoR1.brd]
2018-11-13 Fix J1 DC-044 pin drilling; fix J7 dip male header 2X3P pin diameter.
    [AdelinoR1.brd, AdelinoR1.sch]
2018-11-13 Fix J1 DC-044 pin drilling; fix J7 dip male header 2X3P pin diameter; get rid of bogus wire stubs.
    [AdelinoR1.brd, AdelinoR1.sch]
2018-11-20 Adelino R2 wip.
    [AdelinoR2.brd, AdelinoR2.sch]
2018-11-20 Add alternative TQFP44 socket alongside QFN44.
    [AdelinoR2.brd, AdelinoR2.sch]
2018-11-20 Getting proper double-socket pairing; minor tweaks.
    [AdelinoR2.brd, AdelinoR2.sch]
2018-11-20 Double socket TQFP44+QFN44 finished.
    [AdelinoR2.brd, AdelinoR2.sch]
2018-11-29 Power supply routing wip.
    [AdelinoR2.brd, AdelinoR2.sch]
2018-12-01 Fix USB connector D+/D- wiring.
    [AdelinoR1.brd, AdelinoR1.sch]
2018-12-03 Add revision 2B preserving TX/RX led compatibility.
    [AdelinoR2B.brd, AdelinoR2B.sch]
2018-12-04 Update GPIO0 wires.
    [AdelinoR2B.brd, AdelinoR2B.sch]
2018-12-04 Remove redundant resistor from GPIO0 wiring.
    [AdelinoR2B.brd, AdelinoR2B.sch]
2018-12-04 Add TVS to protect power input.
    [AdelinoR2.brd, AdelinoR2.sch]
2018-12-04 Test changes on reset switch reading.
2018-12-04 Adding native SPI support.
    [AdelinoR2B.brd, AdelinoR2B.sch]
2018-12-05 ATmega/Esp control pins reviewed.
    [AdelinoR2B.brd, AdelinoR2B.sch]
2018-12-05 Reserve resistor for GPIO16/RESET.
    [AdelinoR2B.brd, AdelinoR2B.sch]
2018-12-05 Add '8266 is 5V tolerant' reference link.
2018-12-07 Adjust drill position.
    [AdelinoR2.brd]
2018-12-10 Routing wip.
    [AdelinoR2.brd, AdelinoR2.sch]
2018-12-12 Fix DC-044-A footprint.
    [AdelinoR2.brd, AdelinoR2.sch]
2018-12-13 Add ATECC608 crypto chip; routing wip.
    [AdelinoR2.brd, AdelinoR2.sch]
2018-12-17 Add decoupling cap for ECC608.
    [AdelinoR2.brd, AdelinoR2.sch]
2018-12-18 Routing wip and DRC.
    [AdelinoR2.brd]
2018-12-18 Base X2 routing finished.
    [AdelinoR2.brd]
2018-12-18 Routing revision wip.
    [AdelinoR2.brd]
2018-12-18 Add Adelino X2 schematics.
2018-12-18 Link schematics directly to raw png file.
2018-12-20 Reset status updated to use Adelino X2 port PD5.
    [01-ResetStatus.ino]
2018-12-22 Add 15V TVS from Shenzhen OPL.
    [AdelinoR2.brd, AdelinoR2.sch]
2018-12-24 Route 3.3V decoupling caps away from ESP-12F.
    [AdelinoR2.brd]
2018-12-26 Added assembly placement.
    [AdelinoR2.brd]
2019-01-04 Update readme and X2 schematics png.
2019-01-04 ResetEsp test case working with Adelino X2.
    [02-ResetEsp.ino]
2019-01-04 Add testcase for ESP-AVR SPI high speed bridge.
2019-01-05 New feature: hold reset for 2 seconds to stay in programming mode (or: do not start sketch); Update ACT led to PD5; Add cylon breathing effect.
    [Adelino.c]
2019-01-05 Adopt valid USB VID/PID provided by Microchip Inc.
2019-01-08 Add I2C scan test case for AVR.
2019-01-08 Add I2C scan test case for ESP.
2019-01-10 Add DNP for 32U4 TQFP and ECC608; add some silk art for Adelino X2.
    [AdelinoR2.brd, AdelinoR2.sch]
2019-01-10 Add Adelino X2 silkscreens and component position cues.
    [AdelinoR2.brd, AdelinoR2.sch]
2019-01-10 Better directory structure plus cleanup.
    [AdelinoR1.brd, AdelinoR1.sch, AdelinoR2.brd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]
2019-01-11 Little improvements for Assembly Drawing gerber.
    [AdelinoR2.brd]
2019-01-11 Added gerber files and BOM for SeeedStudio PCBA.
    [AdelinoR2-Eagle-BOM.csv, AdelinoR2-Seeed-BOM.csv]
2019-01-14 Fix linux usb stack mess with changing VID/PIDs; reformat source; the byte diet continues.
    [Adelino.c]
2019-01-15 Change TIMER1 ticks interval from 1ms to 40ms.
2019-01-16 Preparing pcb for Revision A.
    [AdelinoR2.brd, AdelinoR2.sch]
2019-01-16 Better ground plane polygon, avoiding swps areas.
    [AdelinoR2.brd]
2019-01-17 PCBA files for Adelino X2 rev A candidate.
    [AdelinoR2-Seeed-BOM.csv]
2019-01-25 Update BOM; reposition some component labels.
    [AdelinoR2-Eagle-BOM.csv, AdelinoR2.brd]
2019-01-28 Preparing USART0 I/O; fix esptool.py RTS reset error; add ESP reset.
    [Adelino.c]
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2019-02-01 Better GPIO0 sync during ESP8266 reset.
    [Adelino.c]
2019-02-03 Fix receive logic within ISR; miscelaneous size optimizations and a simplified 256-byte ring buffer.
    [Adelino.c]
2019-02-08 Fix misplaced timeout; misc cleaning.
    [Adelino.c]
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2019-04-01 Start X3 revision, mostly 0402->0603.
    [AdelinoX3.brd, AdelinoX3.sch]
2019-04-01 Wip; use same parts as Seeeduino for SPS.
    [AdelinoX3.brd, AdelinoX3.sch]
2019-04-01 Schematic changes to 0603 done.
    [AdelinoX3.brd, AdelinoX3.sch]
2019-04-15 First X3 routing finished.
    [AdelinoX3.brd, AdelinoX3.sch]
2019-04-15 Routing review in progress.
    [AdelinoX3.brd, AdelinoX3.sch]
2019-04-16 Routing review finished.
    [AdelinoX3.brd]
2019-04-17 Board review 1 (ground plane).
    [AdelinoX3.brd]
2019-04-18 Board review 2 (vias and silk).
    [AdelinoX3.brd]
2019-04-19 Fix polygon instead of wire on +5V root.
    [AdelinoX3.brd]
2019-04-19 Add Adelino qrcode and proper brazilian flag proportions.
    [AdelinoX3.brd]
2019-04-19 Parts renumbered; tidy up silkscreen.
    [AdelinoX3.brd, AdelinoX3.sch]
2019-04-22 Add sensing pads; close vias; better test pad spacing.
    [AdelinoX3.brd, AdelinoX3.sch]
2019-04-22 Change bitmaps resolution to be more compatible.
    [AdelinoX3.brd, AdelinoX3.sch]
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2019-04-22 Add Eagle and Seeed BOM files.
    [AdelinoX3_BOM.ods, AdelinoX3_BOM_Eagle.csv, AdelinoX3_BOM_Seeed.csv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]
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2019-04-28 Add reference for ESP8266 5V tolerance declaration from Teo Swee Ann.
2019-04-28 Fix via sizes.
    [AdelinoX3.brd]
2019-05-14 Fix swapped Grove I2C and UART.
    [AdelinoX3.brd]
2021-05-30 Use optimal bundled library names
    When multiple libraries contain files matching an #include directive in the program, the Arduino build system must pick
    one to use for compilation. Multiple factors are used in order to make an intelligent determination of which library is
    best.
    In order to enhance this determination, the closeness of match between the library.properties name value and the
    filename in the #include directive is being added as one of those factors. This new factor is referred to as
    "Library Name Priority".
    Unfortunately, this change can result in platform bundled libraries which had previously been correctly correctly chosen
    no longer being given priority over their equivale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
2023-06-05 Circuito de reset por pulso.
